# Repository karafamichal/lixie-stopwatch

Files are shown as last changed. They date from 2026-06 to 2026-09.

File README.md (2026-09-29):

# Lixie StopWatch

An open-source, Wi-Fi-connected time-tracking device that combines retro
Lixie (pseudo-Nixie) tube aesthetics with modern IoT. Tap a touch screen,
pick a client, project, app category and tool, watch the LED digits count up, and submit
the session to a self-hosted backend with one tap. All clients, projects
and time logs live on a Flask + SQLite server you control; a React
dashboard gives you full CRUD, live status, reports and a remote-control
mirror of every device's screen.

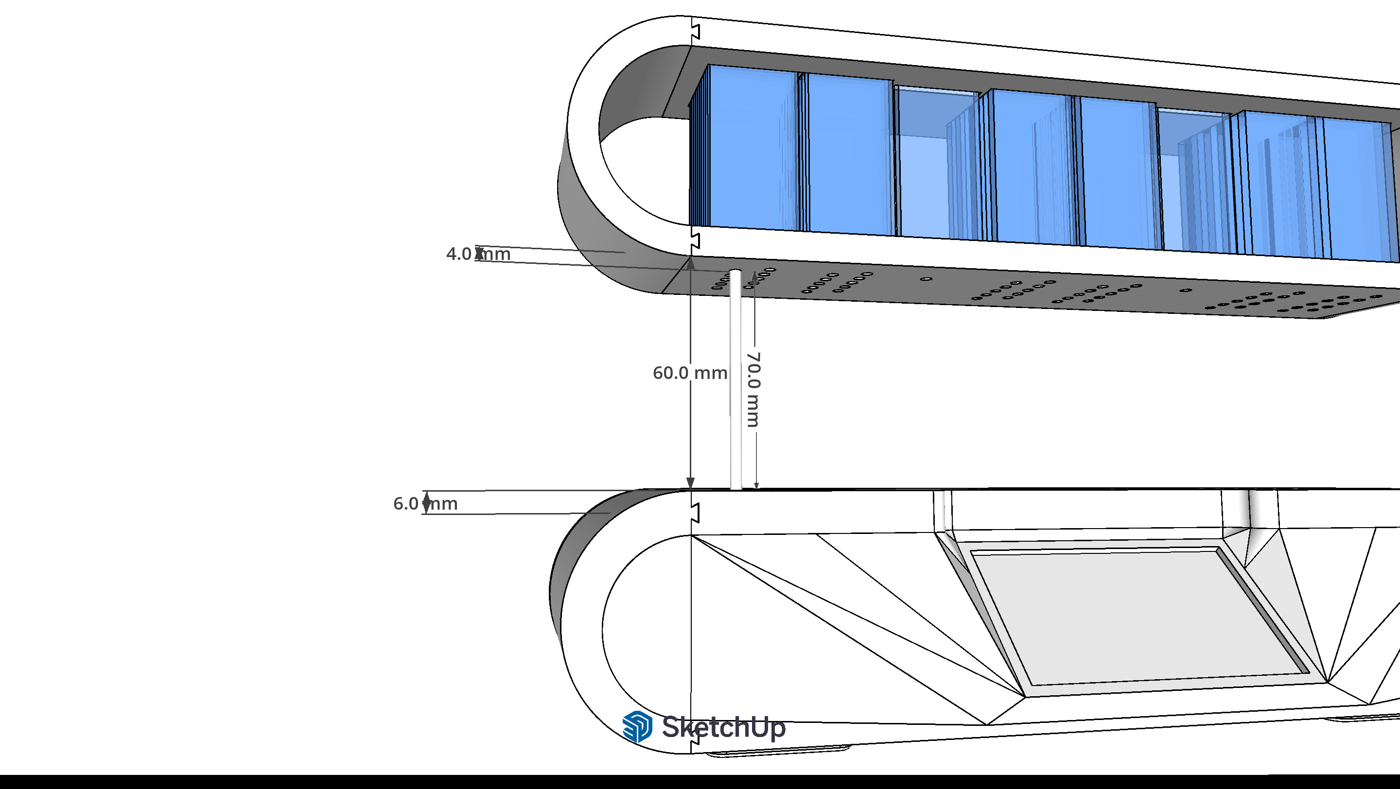
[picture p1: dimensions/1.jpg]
Front view


---

## What it does

* **6-digit Lixie display (HH:MM:SS)** — 75 WS2812B LEDs on 3× 5×5 boards,
  light shining through engraved cast-acrylic tiles to give a floating
  3-D digit effect. The two colon dots flip on/off in lock-step with the
  visible seconds.
* **Touch UI on a 3.2" Nextion display** — guided picker walks you
  through **client → project → category → app**, then Start. The
  category step groups your apps so you don't have to scroll past every
  tool. Pause / Continue / Stop / Discard on screen, with the project
  name shown in its own colour during a session.
* **Breadcrumb navigation** — each selection screen's header shows the
  path you've taken (e.g. `Acme Corp / Site redesign / Design`), so it's
  always clear how deep you are.
* **Wi-Fi onboarding via captive portal** — no need to flash credentials
  into the firmware. Plug in a fresh device, it brings up
  `LixieStopWatch-Setup`, you join it from a phone and pick your home /
  office network from a list.
* **Self-hosted Flask backend + React dashboard** — clients, projects,
  pricing, time logs, devices and reports. Mobile-friendly UI works on
  phones too.
* **Live state over WebSocket** — the dashboard sees every device's
  running state within ~1 s and renders a per-second timer that drifts
  forward locally between server pushes.
* **Remote control mirror** — a faithful 400×240 React render of the
  device's screen; click anywhere on it to inject a touch as if you'd
  tapped the physical Nextion. Operate the unit blind from the dashboard.
* **Per-device LED + display settings** — clock colour, LED brightness,
  an independent colour for the blinking colon dots, **Nextion backlight
  brightness (0–100 %; 0 = display off)**, and an **auto-sleep timeout**
  with an optional "also sleep on idle" toggle. All editable from the
  dashboard and persisted in NVS on the device.
* **English / German touch-screen UI** — every label on the Nextion
  display is translated. Switch on the device itself (☰ → Settings →
  *Language: English / Deutsch*, with live preview before you Save) or
  from the dashboard's device settings; the choice is persisted in NVS
  and the dashboard's remote-control mirror follows it automatically.
* **Auto-sleep view** — after the configured timeout the touch display
  dims to a minimalist icon-only screen (stopwatch glyph while running,
  coffee cup while paused or idle) so the panel isn't distracting in a
  shared workspace. Tap anywhere to wake back to where you were.
* **Weather + RSS news on the idle screen** — auto-derived from public
  IP, no API keys required. Headline rotates every 8 s and the
  background fetch only runs while the device is idle so timing during a
  session is never disturbed.
* **Offline-safe saving** — if the server can't be reached when you save
  a session, the device keeps it (up to 16) and re-sends it once a minute
  while idle. The dashboard shows how many are waiting per device.
* **Pomodoro mode** — optional focus blocks (e.g. 25 min): the LED digits
  count down, the session pauses for the break (green countdown), and the
  digits blink when it's time to continue.
* **"Forgot to start?" reminder** — after a configurable idle stretch on
  the home screen the device asks, and the LEDs blink until someone taps.
* **Night mode** — the LED matrix dims (or switches off) during set hours,
  but lights up normally while a session is running.
* **Firmware updates over Wi-Fi** — upload a `.bin` in the dashboard
  (Settings → Device firmware) and install it per device; the device waits
  until no session is running, verifies the image and restarts.
* **Dashboard extras** — English / German UI, light / dark theme, login
  password, hour budgets per project with warnings, CSV export of time
  logs, printable billing statements and reports (save as PDF), currency
  setting, and one-click database backup / restore.

---

## Project layout

```
nextion-stopwatch/     ESP32-S3 firmware (Arduino sketch + headers)
web-dashboard/
  backend/             Flask REST API + WebSocket hub + SQLite
  dashboard/           React + Vite + Tailwind admin SPA
3d/                    STL files for the case (print-ready)
dimensions/            Photos with measurements + assembly references
Lixie StopWatch — Build Estimate.xlsx
                       Per-unit BOM and time estimate (live formulas)
API.md                 REST + WebSocket reference
nextion-stopwatch/HMI_SETUP.md
                       Steps to build the minimal Nextion HMI file
install.sh             One-shot installer for the backend on a server
lixie-stopwatch.service
                       Systemd unit installed by install.sh
LICENSE                MIT
```

---

## Bill of materials — what one unit costs you

Slovak retail prices (techfun.sk + a hobby laser-cut service), mid-2026.
**Power supply, switch and heavy cabling are not included** because they
depend on how bright you run the LEDs (USB-C from the dev board is enough
at low/medium brightness; for full brightness on all 75 LEDs use a
separate 5 V / 5 A+ supply).

| Item | Qty | Unit | Total |
|---|---:|---:|---:|
| ESP32-S3 N16R8 dev board | 1 | 9.65 € | 9.65 € |
| Nextion 3.2" touch display | 1 | 49.20 € | 49.20 € |
| WS2812 5×5 RGB LED matrix board | 3 | 4.70 € | 14.10 € |
| Wires for connecting everything | 1 | 6.00 € | 6.00 € |
| 3 mm optical fibre, 5 m | 5 m | 0.75 €/m | 3.75 € |
| **Electronics subtotal** | | | **82.70 €** |
| Cast plexiglass sheet (3 mm) | 1 | 8.00 € | 8.00 € |
| Laser cutting + engraving (paid service, ~45 min) | 1 | 45.00 € | 45.00 € |
| **Optics subtotal** | | | **53.00 €** |

**3D-printed case — pick one:**

| Scenario | Detail | Cost |
|---|---|---:|
| A. You own a 3D printer | 500 g PETG + ~1.7 kWh (our reference: Prusa MK4s, 19 h 14 min) | 13.00 € |
| B. You pay a 3D-print service | 500 g PETG @ ~0.12 €/g | 60.00 € |

**Grand totals**

| Scenario | Total per unit |
|---|---:|
| **A — own 3D printer** | **148.70 €** |
| **B — paid print service** | **195.70 €** |
| A* — AliExpress route + own printer (3–5 week shipping wait) | 121.65 € |
| B* — AliExpress route + paid print | 168.65 € |

Full breakdown with live formulas, alternatives and assumptions:
[`Lixie StopWatch — Build Estimate.xlsx`](Lixie%20StopWatch%20%E2%80%94%20Build%20Estimate.xlsx).

### Tools / consumables you'll also need
Soldering iron, helping-hands stand, multimeter, USB-C cable, hot-glue or
super-glue for fibre seats, fine sandpaper for the laser-cut tiles.

---

## 3D-printable parts

All STL files are in [`3d/`](3d/). Print orientation, supports and
materials are noted below. Total filament for the full set: **≈ 500 g
PETG**, total print time **≈ 19 h 14 min on a Prusa MK4s** (0.2 mm layer
height, 15 % gyroid infill, no supports needed if you respect the
overhang directions below).

| File | What it is | Notes |
|---|---|---|
| `esp-top.stl` | Top shell of the electronics bay | Print right-side-up |
| `esp-back-wall.stl` | Rear wall with cable cut-outs | — |
| `esp-bootom-new.stl` | Main bottom plate of the electronics bay | — |
| `esp-bootom-left.stl` / `esp-bootom-right.stl` | Side plates | Print with the mounting boss down |
| `numbers-backwall.stl` | Back wall behind the digit matrices | Black PETG looks best |
| `glass-fullv2.stl` | Main front frame holding the engraved tiles | — |
| `glass-full-top-v2.stl` | Cap that closes the front frame from above | — |
| `glass-side2x.stl` | Side spacer × 2 (print twice) | — |
| `display-lixie-final2.stl` | Bezel for the Nextion touch panel | Tight fit — calibrate flow |
| `foot.stl` | Foot rest, print ×2 | — |

---

## Dimensions & assembly references

Pictures with measurements live in [`dimensions/`](dimensions/). They
show how everything fits together; numbers on them match the STLs above.

| Picture | What it shows |
|---|---|
|  | Assembled unit, front |
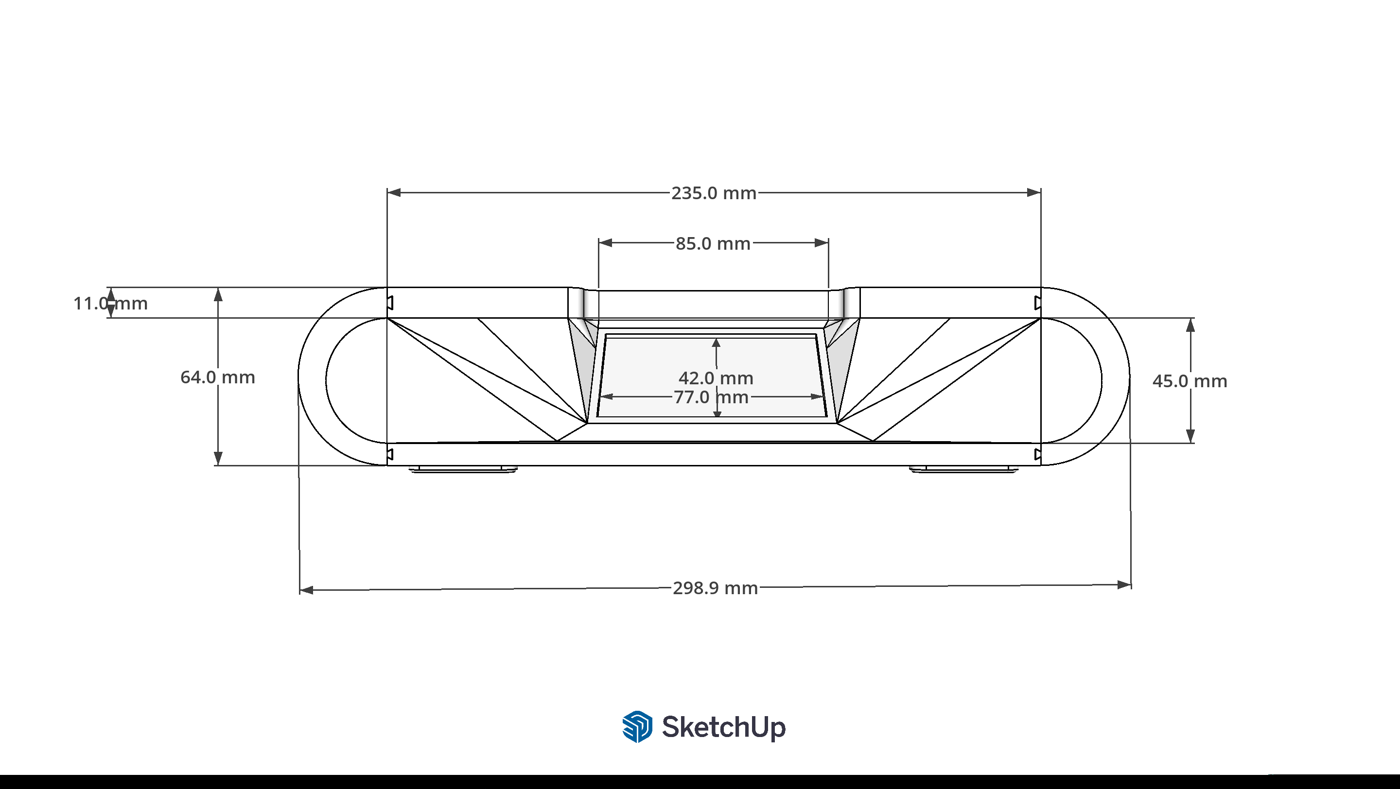
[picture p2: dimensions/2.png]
|  | Front-frame dimensions |
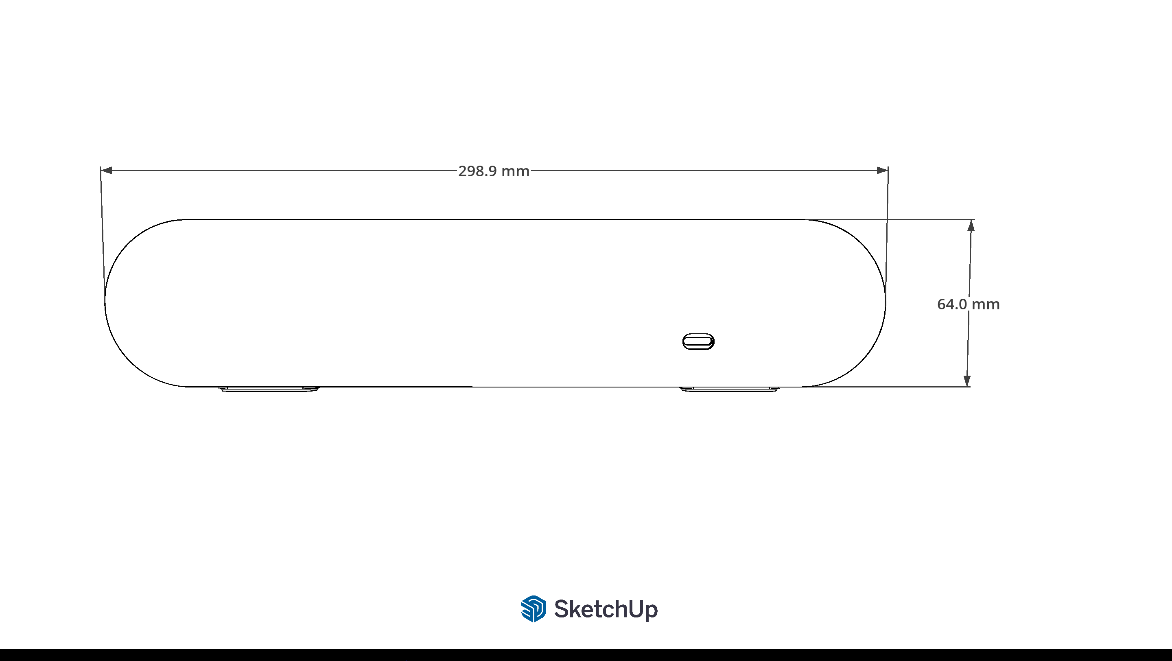
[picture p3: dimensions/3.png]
|  | Side profile |
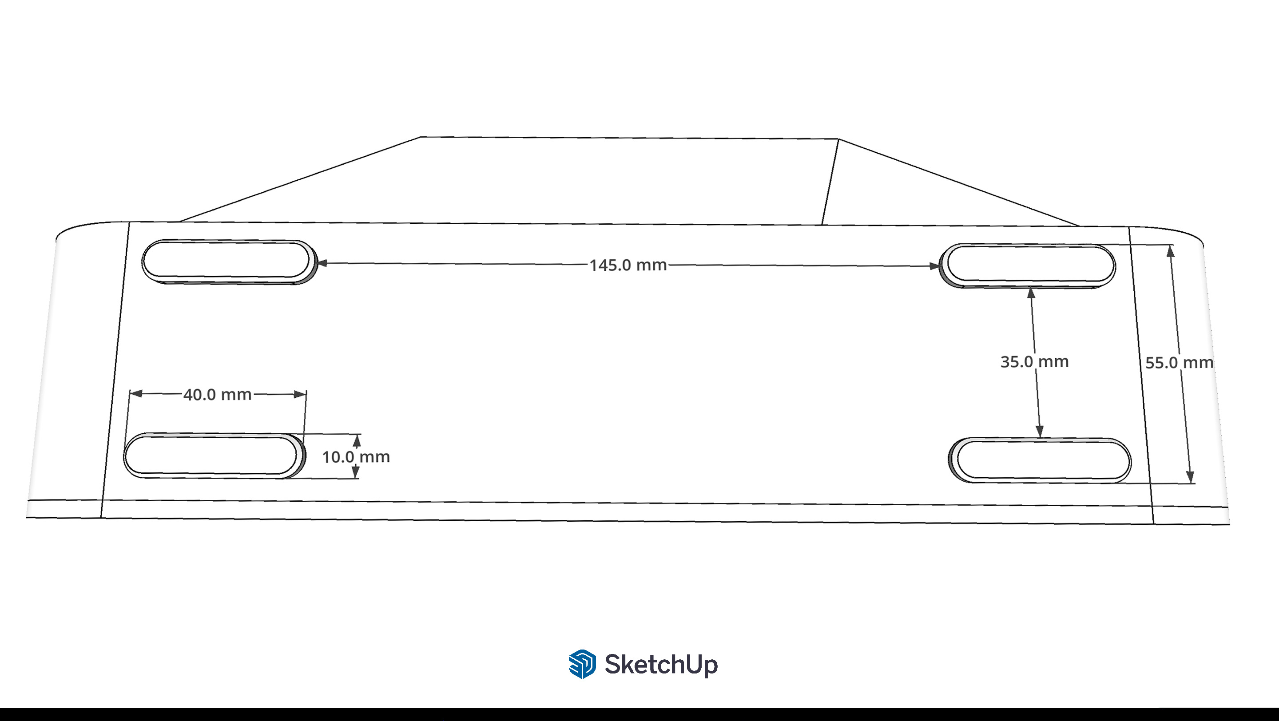
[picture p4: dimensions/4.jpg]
|  | Engraved tile stack-up |
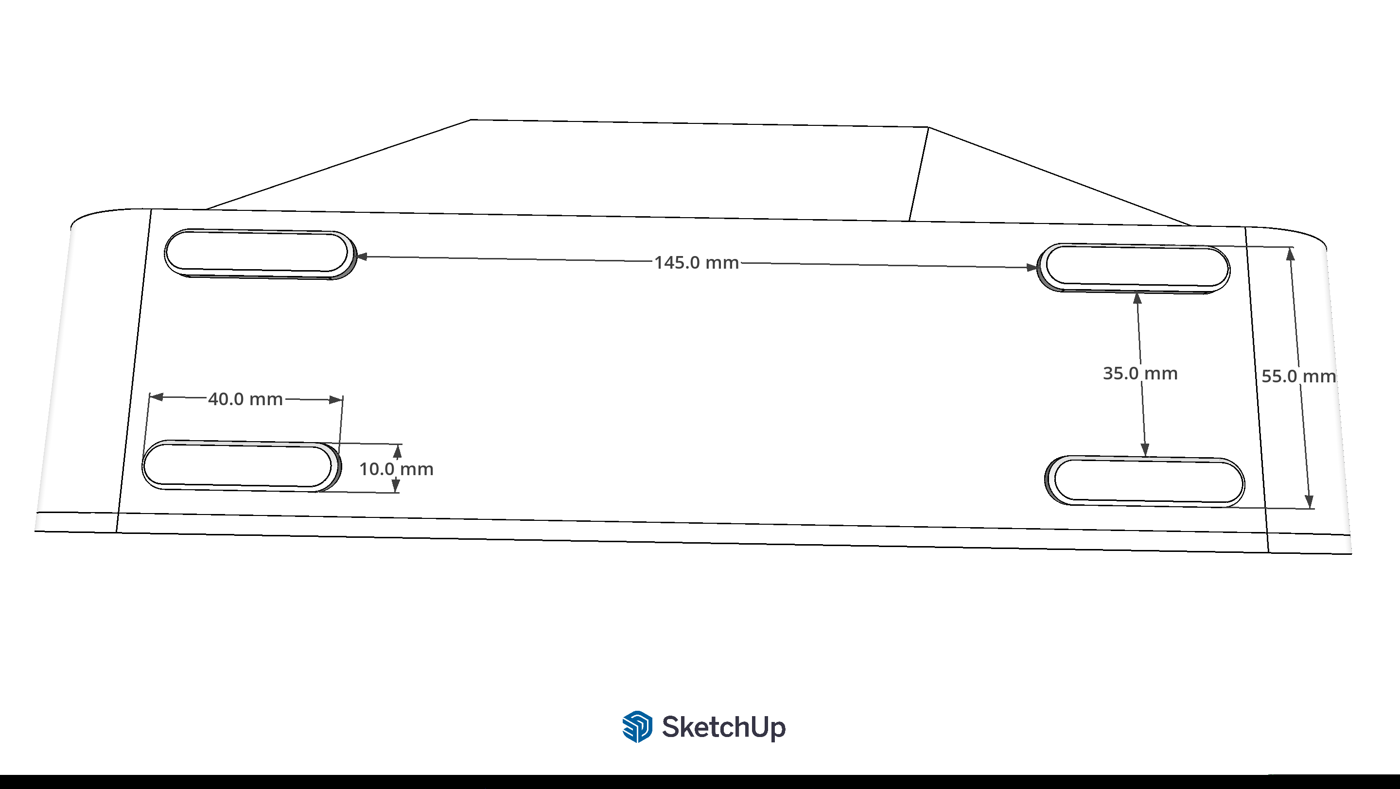
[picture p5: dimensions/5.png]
|  | Back-wall layout |
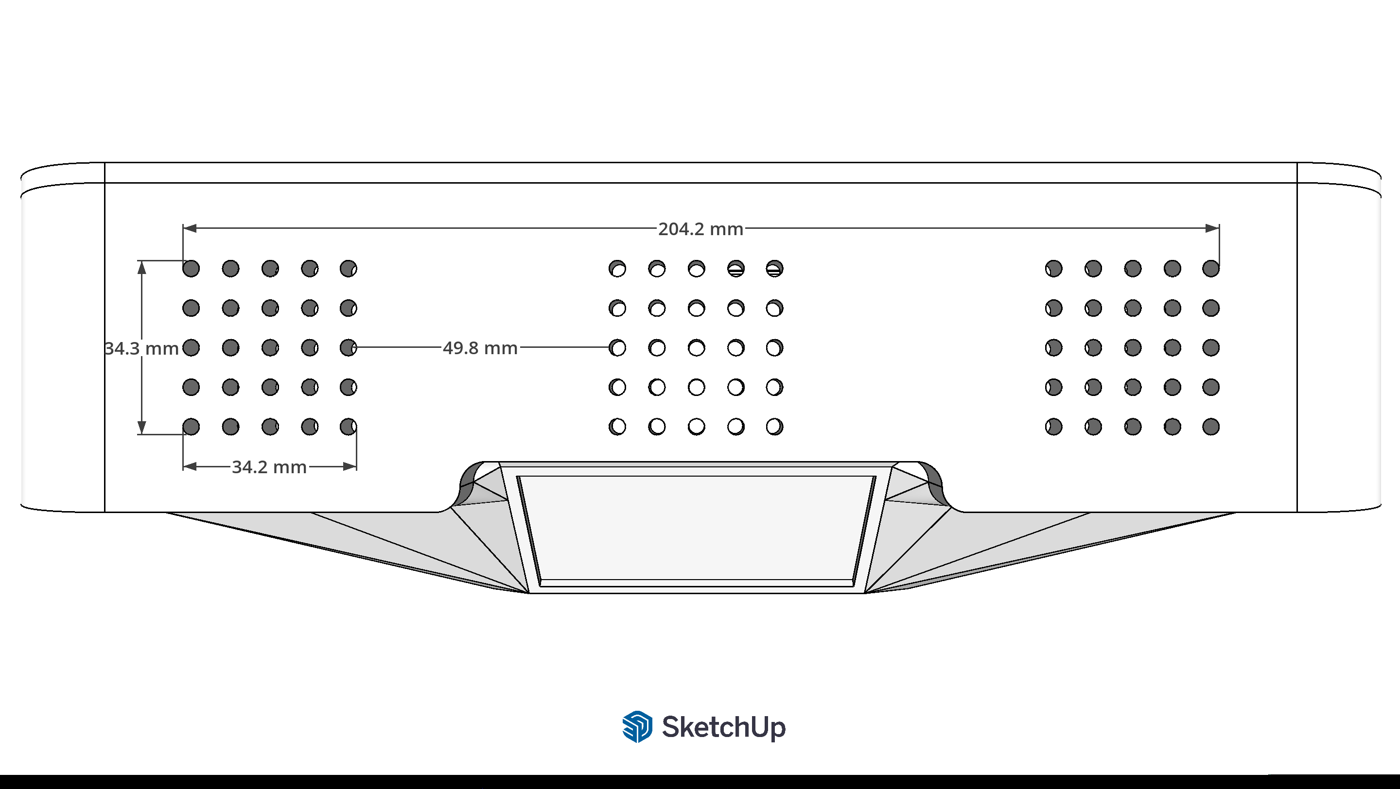
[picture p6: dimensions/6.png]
|  | Matrix-board placement grid |
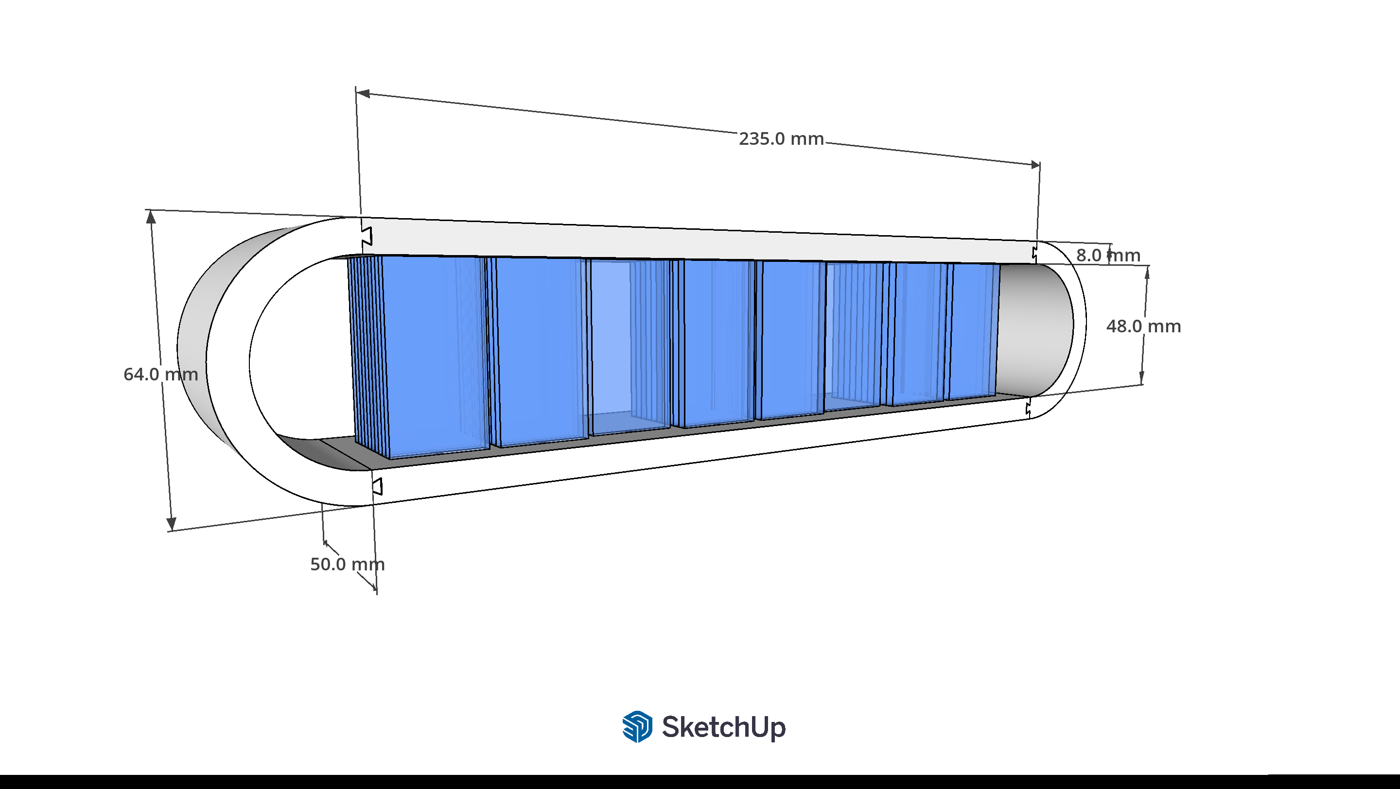
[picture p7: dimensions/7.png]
|  | Optical-fibre routing |
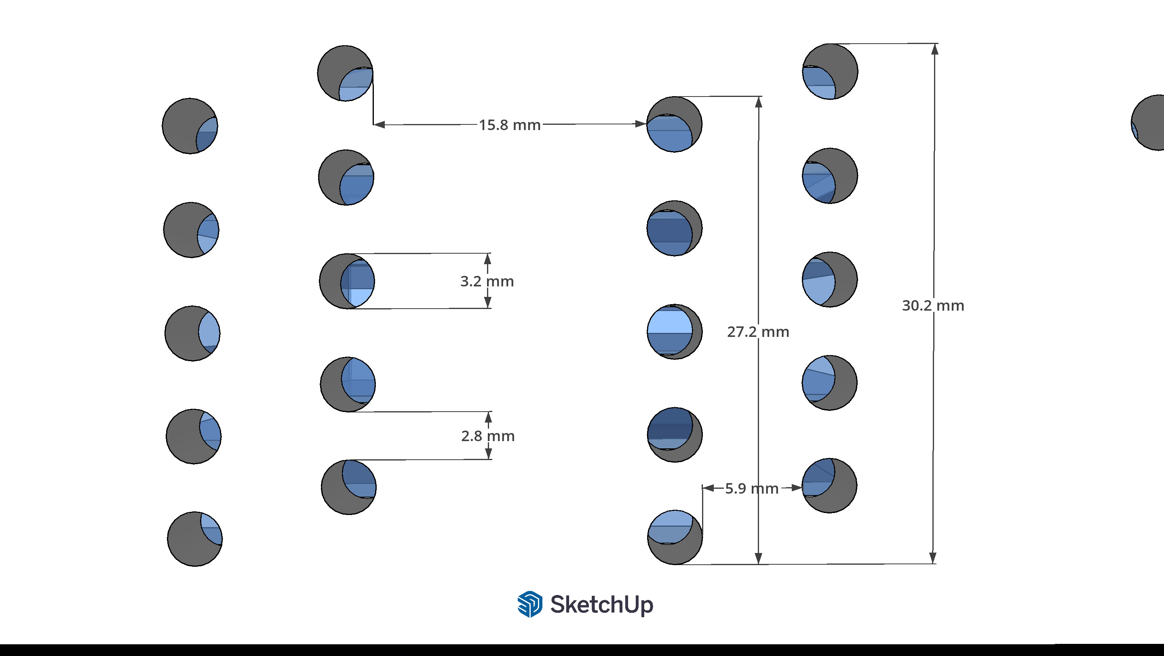
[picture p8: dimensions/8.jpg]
|  | Nextion bezel mounting |
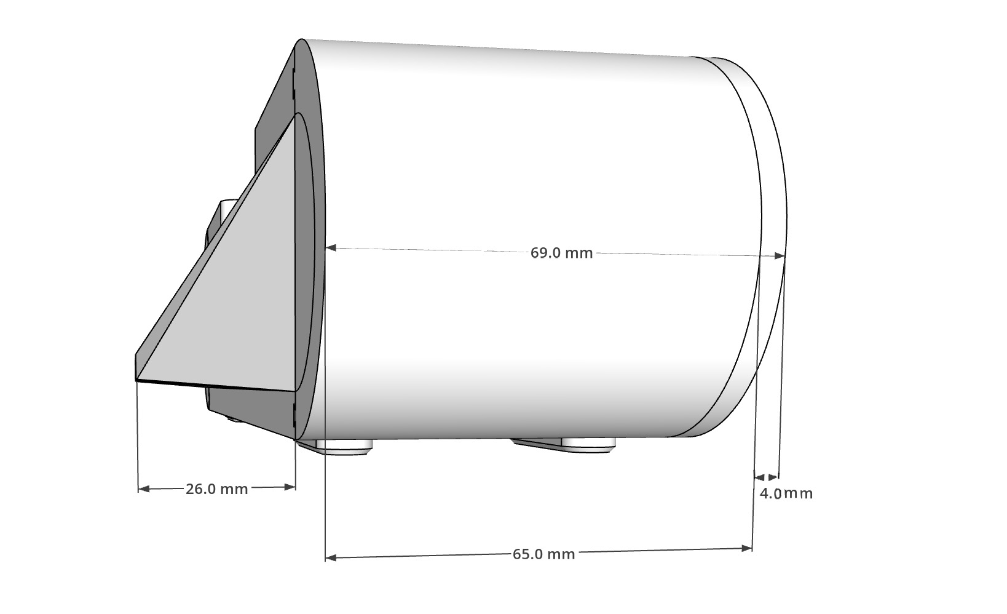
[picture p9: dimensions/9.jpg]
|  | Cable run for the LED chain |
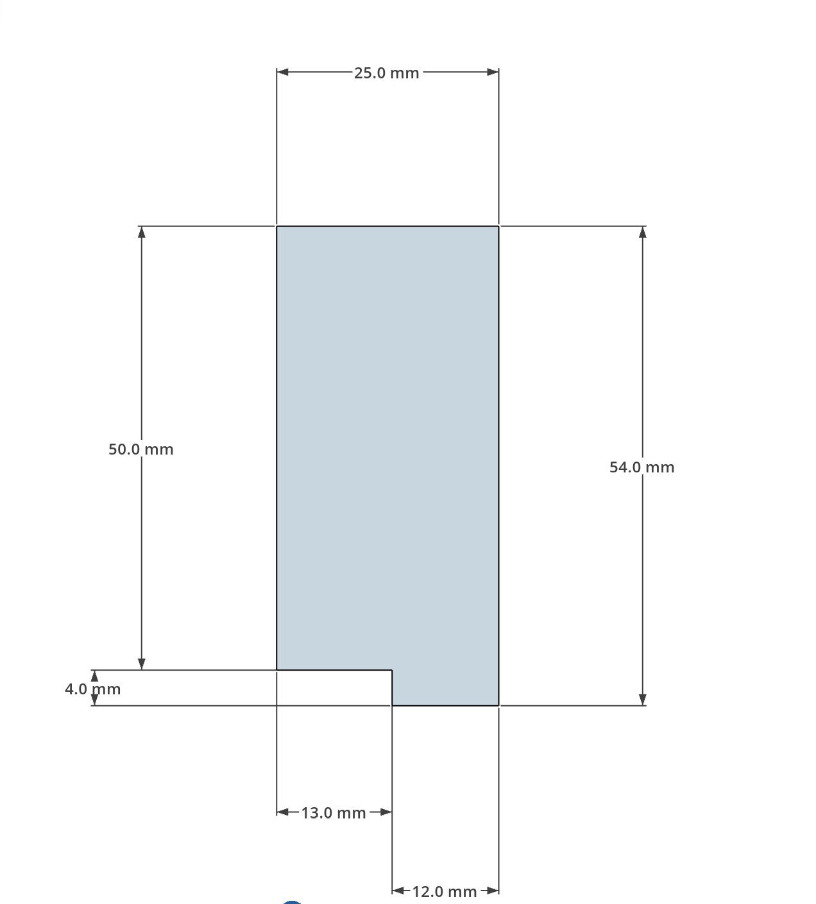
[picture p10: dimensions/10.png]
|  | ESP32 + Nextion wiring diagram |
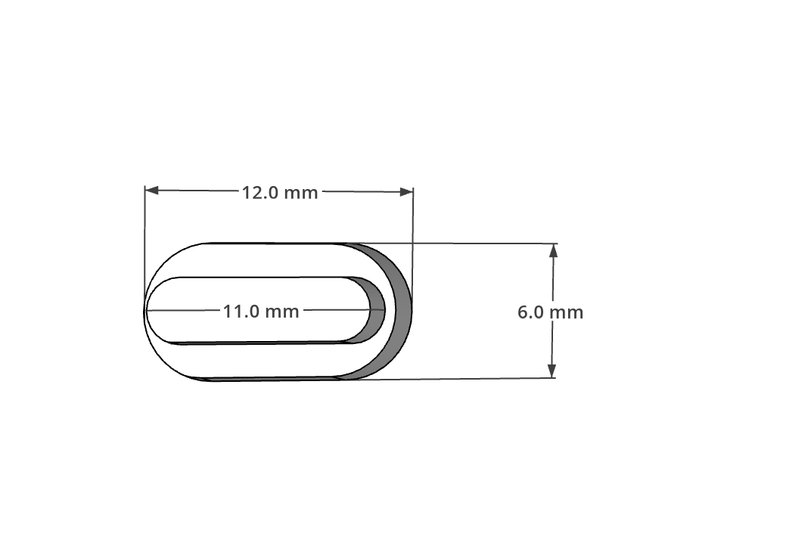
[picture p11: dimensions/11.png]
|  | Foot mounting |
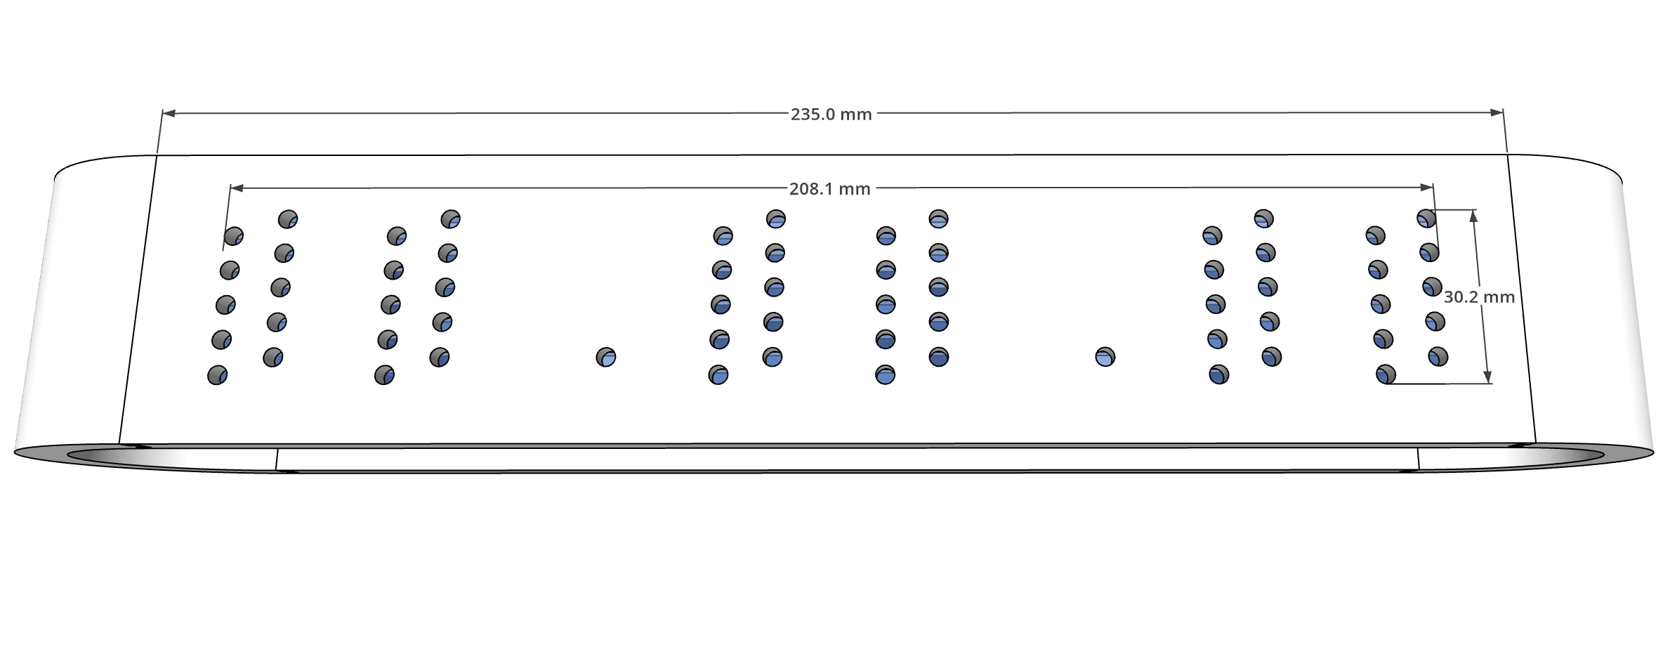
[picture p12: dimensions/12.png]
|  | Final exploded view |

---

## Build & assembly walk-through

1. **Print the case.** All 11 STLs from `3d/`. PETG is recommended near
   the power input; PLA is fine for the front frame.
2. **Cut 60 engraved tiles** — 10 layers of digits 0–9 per digit × 6
   digits — from 3 mm cast acrylic on a laser cutter. Vector source is
   embedded in the STL set; any hobby laser service can do this for you
   from the included engraving template.
3. **Solder the LED chain.** WS2812B 5×5 boards in series: DIN of board 1
   to GPIO 5, DOUT to DIN of board 2, etc. Insert each colon LED at the
   indices defined in `nextion-stopwatch/ledmap.cpp`.
4. **Wire the Nextion.** See [`nextion-stopwatch/HMI_SETUP.md`](nextion-stopwatch/HMI_SETUP.md)
   — it covers the pinout (GPIO 17/18 UART) and how to build the minimal
   HMI file from scratch.
5. **Slot the engraved tiles into the front frame** with optical fibres
   threaded from each LED to its tile. Refer to `dimensions/7.png` for
   the routing pattern.
6. **Close up the case**, plug in USB-C, and follow [First boot](#first-boot).

---

## Server installation (Linux, one-shot script)

The Flask backend + React dashboard live on any machine with Python 3.11+,
Node 18+ and a network reachable by the stopwatches. The included
[`install.sh`](install.sh) does everything for Debian/Ubuntu.

```bash
# On the server, as a normal user
unzip lixie-stopwatch-<version>.zip      # or git clone …
cd lixie-stopwatch
sudo bash install.sh
```

What the script does:

1. `apt install` Python venv tooling, Node + npm, build tools.
2. Creates a system user/group called **`lixie`**.
3. Copies the source tree to `/opt/lixie-stopwatch/`.
4. Creates a Python virtualenv at `/opt/lixie-stopwatch/venv/` and runs
   `pip install -r backend/requirements.txt`.
5. Runs `npm ci && npm run build` in the dashboard, copies the build
   into `backend/static/` so Flask serves the SPA on port 5000.
6. Installs `lixie-stopwatch.service` to `/etc/systemd/system/`, enables
   it and starts it.

When it finishes, the dashboard is reachable at `http://<server>:5000/`
and the API at `http://<server>:5000/api/v1/`. The database file lives
at `/opt/lixie-stopwatch/backend/instance/lixie.db` and is preserved on
re-runs of the script.

Re-run `sudo bash install.sh` after any code update to rebuild and
restart — the script is idempotent and the SQLite database in
`instance/` is excluded from the rsync.

### Verifying
```bash
systemctl status lixie-stopwatch.service
journalctl -u lixie-stopwatch.service -f
curl -s http://localhost:5000/api/v1/stats | python3 -m json.tool
```

### Reverse proxy / HTTPS
If you want HTTPS or a friendly hostname, point an Nginx / Caddy / Apache
vhost at `http://127.0.0.1:5000`. The WebSocket at `/api/v1/ws` upgrades
correctly through standard reverse-proxy WS configs — no extra path
gymnastics needed.

---

## Firmware install (ESP32-S3)

The firmware is a plain Arduino sketch in
[`nextion-stopwatch/`](nextion-stopwatch/).

1. Install **Arduino IDE 2.x**, add the **esp32 by Espressif Systems**
   board manager URL
   `https://espressif.github.io/arduino-esp32/package_esp32_index.json`
   and install the latest package.
2. Pick board **ESP32S3 Dev Module**, PSRAM **OPI PSRAM**, Flash size
  **16 MB**, and partition scheme **16M Flash (3MB APP/9.9MB FATFS)**.
  The default scheme has a 1.25 MB app slot and is too small for this
  firmware.
3. Install the libraries (Sketch ▸ Include Library ▸ Manage Libraries):
   - `FastLED`
   - `ArduinoJson` (v7)
   - `WebSockets` by Markus Sattler
4. Open `nextion-stopwatch/nextion-stopwatch.ino` and flash.

Later updates can go over Wi-Fi: bump `FW_VERSION` in `config.h`, use
**Sketch ▸ Export Compiled Binary**, upload the `.ino.bin` under
Settings → Device firmware in the dashboard, then press the install button
next to the device on the Devices page. This needs a partition scheme with
two app slots — the one above has them.

On a brand-new device the firmware tries the placeholder Wi-Fi in
`config.h` (`changeme` / `changeme`), fails, and brings up the captive
portal — keep reading.

---

## First boot

1. Power the device.
2. On a phone or laptop, join the open Wi-Fi **`LixieStopWatch-Setup`**.
3. A captive portal should open automatically — if not, browse to
   `http://192.168.4.1/`.
4. Pick your home / office Wi-Fi from the list, enter the password, hit
   **Save**. If your dashboard server is not the build-time default, fill
   in its IP / hostname and port on the same page. The device stores it
   all to NVS and reboots.
5. From then on it auto-connects to that network at every boot. To
   change networks later, hold the front face during boot until you see
   the AP mode banner — or temporarily move it out of range of the saved
   network and it'll fall back to AP mode by itself.

Now go to the dashboard at `http://<your-server>:5000/`:

* **Devices** page shows your stopwatch as **Online** within ~5 seconds
  of the first WebSocket connect.
* Click the **palette** icon to set per-device matrix settings:
  - **Clock colour** and **LED matrix brightness** (Low / Med / High / Max)
  - **Colon dot colour** — independent from the clock colour, with a
    *link* toggle that keeps them in sync when on
  - **Touch display brightness** — 0–100 % slider; 0 % turns the Nextion
    backlight all the way off
  - **Auto-sleep** — seconds of inactivity before the screen dims to the
    icon-only sleep view (0 disables); a switch lets you extend the
    timeout to the idle screen too
  - **Touch display language** — English or Deutsch for the Nextion UI
    (the dashboard itself stays in English)
* Click the **mirror screen** icon to remote-control the unit from the
  browser. The mirror reproduces every screen — including the sleep
  view — and clicks are converted to device pixels and posted as a
  synthetic touch.
* In **Clients** create your first client, then a project under it.
  Under **Pricing** add any custom apps you want grouped per category
  (Design / Development / Office / …). On the device the picker walks
  the user through **Client → Project → Category → App** with three
  rows per screen so there's no scrolling past every tool.

---

## What you might want to change in the code

Out of the box the captive portal + the pre-configured RSS feed mean
**most people don't have to edit anything**. If you want to:

| What | Where |
|---|---|
| Default server hostname / IP and port (the captive setup page can override them) | `nextion-stopwatch/config.h` → `WS_HOST`, `WS_PORT` |
| Default LED brightness and colour | `nextion-stopwatch/config.h` → `LED_BRIGHTNESS`, `COL_ACCENT` (only used until the user overrides them from the dashboard) |
| Time zone | `config.h` → `TZ_STRING` (POSIX TZ syntax) |
| RSS news feed | `config.h` → `NEWS_RSS_URL` |
| Weather fallback city when ip-api.com geolocation fails | `config.h` → `WEATHER_FALLBACK_*` |
| Hardware ID (must be unique per physical unit if you have more than one) | `config.h` → `HARDWARE_ID` |
| LED-to-digit mapping if a segment is dark after soldering | `nextion-stopwatch/ledmap.cpp` → `ledIndex[][]` |
| Service paths / install root | `install.sh` and `lixie-stopwatch.service` |

---

## Power notes

* **USB-C only** — fine at low / medium brightness. The ESP32-S3 dev
  board's USB input can supply ~500 mA, enough for the display and the
  LEDs at brightness up to ~80/255.
* **External 5 V supply** — required if you want full brightness on all
  75 LEDs. Worst case draw is ~4.9 A (75 × 60 mA + the ESP32 and
  Nextion). A 5 V / 5 A+ switching supply is enough; wire it through
  your own switch and a fused barrel jack.
* Add a **1000 µF** electrolytic capacitor across the 5 V rail at the
  head of the LED chain if you see the first frame flash on power-on.

---

## License

[MIT](LICENSE). Use, copy, modify, fork, sell, do whatever you want —
just keep the copyright notice. The 3D models in [`3d/`](3d/) and the
Nextion HMI assets are released under the same terms.

---

## Credits

Built by the Lixie StopWatch team as an Erasmus+ school project (Erfurt
2026). Open-sourced so anyone can build, hack and improve.

Pull requests welcome — especially better case designs, alternative
display drivers, and translations of the dashboard UI.

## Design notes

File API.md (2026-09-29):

# Lixie StopWatch — API Reference

Base URL: `http://<server>:5000/api/v1`

All request bodies are JSON (`Content-Type: application/json`).
All responses are JSON. Dates are ISO 8601 strings (`2026-05-26T14:30:00`).

The server exposes a REST API for everything that doesn't need to be live
(CRUD, reports) and a single WebSocket channel for live state push and
remote control. ESP32 stopwatches and the React dashboard both use the same
endpoints.

### Authentication

The dashboard can be locked with a password (Settings → Dashboard password).
Until one is set, every endpoint is open. Once it is set, every endpoint
answers `401 {"error": "login required"}` without a session cookie, **except**
the ones the ESP32 uses, which stay open so devices need no credentials:

`GET /clients`, `GET /projects`, `GET /apps`, `POST /timelogs`,
`POST /devices/heartbeat`, `GET /firmware/<token>.bin` and the WebSocket
(devices may push `state`; a `subscribe` from a browser without a session
closes the socket).

| Endpoint | Body | Notes |
|---|---|---|
| `GET /auth` | – | `{ "enabled": bool, "authenticated": bool }` |
| `POST /auth/login` | `{ "password": "…" }` | Sets a 30-day session cookie. Wrong password: `401` after a 1 s delay. |
| `POST /auth/logout` | – | Clears the session. |
| `PUT /auth/password` | `{ "current": "…", "new": "…" }` | Sets, changes or (with an empty `new`) removes the password. `current` is required once a password exists; `new` needs at least 6 characters. |

---

## Data model overview

```
client  ──<  project  ──<  time_log  >──  app
                                 \
                                  >──  device
```

One `time_log` row = one completed work session: **who worked, on what
project, for which client, using which app, for how long, on which device.**

### Tables

| Table | Notable columns | Cascade |
|---|---|---|
| `client` | `name`, `active`, `color`, `logo`, `created_at` | — |
| `project`  | `name`, `client_id`, `active`, `color`, `logo`, `completed`, `completed_at` | deleted when client is deleted |
| `app` | `name`, `category`, `icon`, `color`, `logo`, `is_builtin`, `hourly_rate`, `active` | — |
| `device` | `hardware_id`, `label`, `last_seen` | — |
| `time_log` | `device_id`, `client_id`, `project_id`, `app_id`, `start_timestamp`, `duration_seconds`, `notes`, `status`, `synced_at` | `client_id`/`project_id` delete cascades; `app_id`/`device_id` are nullable and kept on delete |

---

## Clients

### `GET /clients`

Returns all clients ordered by name.

```json
[
  {
    "id": 1,
    "name": "Acme Corp",
    "active": true,
    "color": "#FF8000",
    "logo": null,
    "created_at": "2026-05-01T10:00:00"
  }
]
```

### `POST /clients`

| Field | Type | Required | Default |
|---|---|---|---|
| `name` | string | yes | — |
| `active` | boolean | no | `true` |
| `color` | string `#RRGGBB` | no | `#FF8000` |
| `logo` | data URL string | no | `null` |

Returns `201` with the created object.

### `PUT /clients/<id>`

Any subset of `name`, `active`, `color`, `logo`. Returns the updated object.

### `DELETE /clients/<id>`

Cascades: all projects and time logs for this client are also deleted.
`204 No Content`.

---

## Projects

### `GET /projects?client_id=<id>`

**Active** projects only — what the ESP32 consumes when building the
project picker.

```json
[
  {
    "id": 7,
    "client_id": 3,
    "client_name": "Acme Corp",
    "client_color": "#FF8000",
    "client_logo": null,
    "name": "Website Redesign",
    "active": true,
    "color": "#2D8CFF",
    "logo": null,
    "completed": false,
    "completed_at": null,
    "created_at": "2026-05-10T09:00:00"
  }
]
```

### `GET /projects/all?client_id=<id>`

Every project including inactive and completed ones, each with two extra
fields: `budget_hours` (planned hours, `null` = no budget) and
`tracked_seconds` (total logged time).

All projects (active **and** inactive). Dashboard only.

### `POST /projects`

| Field | Type | Required | Default |
|---|---|---|---|
| `name` | string | yes | — |
| `client_id` | integer | yes | — |
| `active` | boolean | no | `true` |
| `color` | hex | no | `#FF8000` |
| `logo` | data URL | no | `null` |

Returns `201`.

### `PUT /projects/<id>`

`POST /projects` and `PUT /projects/<id>` accept `budget_hours` (number ≥ 0;
`null`, `""` or `0` removes the budget), and `led_style` — how the LED
digits look during a session of this project (`""` = client colour):

| `led_style` | Meaning |
|---|---|
| `""` | Plain colour |
| `d:#RRGGBB,…` (6 colours) | One colour per digit, H H M M S S |
| `c:SEC:#RRGGBB,…` (2–8 colours) | All digits fade through the colours, one round every `SEC` (1–3600) seconds |

Any subset of the create fields, plus:

| Field | Type | Notes |
|---|---|---|
| `completed` | boolean | When set `true` the project is auto-deactivated and `completed_at` is stamped to `now`. Setting back to `false` clears `completed_at`. |

### `GET /projects/<id>/billing`

Per-app time and earnings breakdown for one project.

```json
{
  "project_id": 7,
  "project_name": "Website Redesign",
  "total_seconds": 36000,
  "total_earnings": 950.00,
  "breakdown": [
    {
      "app_id": 2,
      "app_name": "Photoshop",
      "app_icon": "🎨",
      "app_color": "#31A8FF",
      "hourly_rate": 95.00,
      "seconds": 18000,
      "hours": 5.0,
      "earnings": 475.00
    }
  ]
}
```

The billing response also carries `client_name`, `first_log` and
`last_log` (ISO timestamps of the earliest and latest time log), used by the
dashboard's printable billing statement.

### `DELETE /projects/<id>`

Cascades all time logs for this project. `204`.

---

## Apps (a.k.a. Pricing tools)

### `GET /apps`

Active apps only, ordered by category then name. Used by the ESP32.

```json
[
  {
    "id": 2,
    "name": "Photoshop",
    "category": "Design",
    "icon": "🎨",
    "color": "#31A8FF",
    "logo": null,
    "active": true,
    "is_builtin": true,
    "hourly_rate": 95.00,
    "created_at": "2026-05-01T10:00:00"
  }
]
```

### `GET /apps/all`

All apps including inactive. Dashboard only.

### `POST /apps`

Create a **custom** (non-built-in) app.

| Field | Type | Default |
|---|---|---|
| `name` | string | required |
| `category` | string | `Other` |
| `icon` | string (emoji) | `🖥️` |
| `color` | hex | `#FF8000` |
| `hourly_rate` | float | `null` |
| `logo` | data URL | `null` |

### `PUT /apps/<id>`

For **built-in** apps only `active`, `hourly_rate` and `logo` can be
changed (name / category / icon / color stay locked). Custom apps accept
the full set.

### `DELETE /apps/<id>`

Returns `400` if `is_builtin`. Time logs that referenced this app keep
their `app_id` value — it's nullable, not cascaded.

---

## Time Logs

### `GET /timelogs`

List time logs, newest first. Filters:

| Param | Type | Description |
|---|---|---|
| `client_id` | integer | filter by client |
| `project_id` | integer | filter by project |
| `app_id` | integer | filter by app |
| `from` | `YYYY-MM-DD` | start of date range (inclusive) |
| `to` | `YYYY-MM-DD` | end of date range (inclusive) |

```json
[
  {
    "id": 42,
    "device_id": 1,
    "hardware_id": "esp32_lixie_001",
    "device_label": "Studio Device",
    "client_id": 3,
    "client_name": "Acme Corp",
    "project_id": 7,
    "project_name": "Website Redesign",
    "app_id": 2,
    "app_name": "Photoshop",
    "app_icon": "🎨",
    "app_color": "#31A8FF",
    "start_timestamp": "2026-05-26T14:00:00",
    "duration_seconds": 5400,
    "notes": "Homepage banner mockups",
    "status": "completed",
    "synced_at": "2026-05-26T15:30:00"
  }
]
```

### `POST /timelogs` — primary ESP32 endpoint

Submit a completed session.

| Field | Type | Required | Notes |
|---|---|---|---|
| `hardware_id` | string | no | Auto-creates a `device` row on first sight and updates `last_seen` on every submission. |
| `client_id` | integer | yes | Must exist. |
| `project_id` | integer | yes | Must exist. |
| `app_id` | integer | no | If omitted/`null`, the session is logged without an app. |
| `start_timestamp` | ISO 8601 | no | UTC preferred (trailing `Z` accepted). Defaults to server time if omitted. |
| `duration_seconds` | integer | yes | Total elapsed seconds the timer ran. |
| `notes` | string | no | Free-text memo. |
| `status` | string | no | `completed` / `pending` / `synced`. Defaults to `completed`. |

Returns `201` with the full time log object.

### `PUT /timelogs/<id>` / `DELETE /timelogs/<id>`

Edit / remove a single entry (dashboard).

---

## Devices

Devices are auto-registered the first time their `hardware_id` appears in
either a `POST /timelogs` call, a heartbeat, or a WebSocket connection.

### `GET /devices`

All known devices, most recently seen first.

```json
[
  { "id": 1, "hardware_id": "esp32_lixie_001", "label": "Studio Device", "last_seen": "2026-05-26T15:30:00" }
]
```

### `POST /devices/heartbeat`

Body: `{ "hardware_id": "esp32_lixie_001" }`. Touches `last_seen` so the
dashboard's online indicator stays accurate between time-log submissions.
First call also auto-registers the device. `204`.

### `PUT /devices/<id>`

Body `{ "label": "Studio Device" }`. Returns the updated device.

### `GET /devices/<id>/settings`

Read the currently-cached LED + display settings for one device.

```json
{
  "hardware_id":        "esp32_lixie_001",
  "color":              "#FF8000",
  "colon_color":        "#FF8000",
  "colon_linked":       true,
  "brightness":         150,
  "display_brightness": 100,
  "sleep_timeout_sec":  30,
  "sleep_on_idle":      false,
  "language":           "en",
  "pomodoro_min":       25,
  "break_min":          5,
  "reminder_min":       0,
  "night_start":        22,
  "night_end":          7,
  "night_brightness":   10,
  "online":             true
}
```

### `PUT /devices/<id>/settings`

Push new LED + display settings to a device. Any subset of fields may
be sent.

| Field | Type | Notes |
|---|---|---|
| `color` | `#RRGGBB` | Clock / stopwatch digit colour |
| `colon_color` | `#RRGGBB` | The two blinking colon dots (independent colour) |
| `clock_style` | `led_style` string | Per-digit colours or colour cycle for the clock (same format as projects' `led_style`); `""` = plain `color` |
| `demo` | boolean | Demo / showcase mode: rainbow animation instead of the idle clock. Sessions still display normally. |
| `colon_linked` | boolean | When `true` the colon colour automatically mirrors `color`; PUTting `colon_color` without an explicit `colon_linked` flips it to `false` |
| `brightness` | `0..255` | LED matrix brightness (single global FastLED setting) |
| `display_brightness` | `0..100` | Nextion backlight, in percent. `0` turns the backlight all the way off (controller still responds to commands). |
| `sleep_timeout_sec` | `0..65535` | Seconds of inactivity before the touch display dims to the icon-only sleep view. `0` disables auto-sleep entirely. |
| `sleep_on_idle` | boolean | When `true`, the sleep timeout also applies to the idle / home screen (coffee-cup icon). When `false`, sleep only triggers from the running session view. |
| `pomodoro_min` | `0..120` | Pomodoro focus block in minutes; `0` turns pomodoro off. The LEDs count down each block, then the session auto-pauses for the break. |
| `break_min` | `1..60` | Break length after each focus block. |
| `reminder_min` | `0..480` | Minutes on the home screen without a touch before the "Forgot to start?" prompt (LEDs blink). `0` = off. Suppressed during night mode. |
| `night_start`, `night_end` | `0..23` | Local hours of the night window (may wrap past midnight). Equal values turn night mode off. |
| `night_brightness` | `0..255` | LED brightness inside the night window (`0` = LEDs off). Normal brightness returns while a session runs. |
| `language` | `"en"` \| `"de"` | UI language of the Nextion touch screen. Also switchable on the device itself (Settings → Language); the device reports its current language in every state push and the server adopts that value, so the two never fight. |

The dashboard-only `colon_linked` flag is stripped before pushing to the
device — the firmware only ever sees `{type:"settings", color,
colon_color, brightness, display_brightness, sleep_timeout_sec,
sleep_on_idle, language}`. Settings are cached server-side and re-sent to the
device the moment it next connects.

Response includes the merged state plus `delivered: true|false`
(`false` = device is currently offline; the cached value will be replayed
on reconnect).

### `POST /devices/<id>/ota`

Tell a connected device to install the firmware uploaded via
`POST /firmware`. The device keeps the request until no session is running,
downloads `GET /firmware/<token>.bin`, verifies it against the `x-MD5`
header and reboots into it. Returns `{ "delivered": bool }` (`false` =
offline, nothing queued). Progress shows up as `ota_status` in the device's
state push.

### `POST /devices/<id>/remote/touch`

Inject a synthetic Nextion touch — used by the Remote Control modal in
the dashboard to operate the device as if you were tapping the physical
screen.

Body:

```json
{ "x": 200, "y": 120, "pressed": true }
```

| Field | Type | Range / default |
|---|---|---|
| `x` | integer | `0..399` (matches device screen) |
| `y` | integer | `0..239` |
| `pressed` | boolean | default `true` (the firmware acts on press, ignores release) |

Response `{ "delivered": true|false }` — `false` means the device was
offline and the touch was dropped (not queued).

### `DELETE /devices/<id>`

Remove the device row. Time logs from this device keep their `device_id`
(orphaned reference, kept for history).

---

## Server settings, backup, firmware

### `GET /settings` / `PUT /settings`

`{ "currency": "EUR" }` — ISO 4217 code used for rates, earnings and
statements. Amounts are stored as plain numbers and never converted.

### `GET /backup`

Downloads a consistent snapshot of the SQLite database
(`lixie-backup-YYYYMMDD-HHMM.db`).

### `POST /backup`

Multipart upload (`file`). The file must be a SQLite database that passes
`PRAGMA integrity_check` and contains the `client`, `project` and `time_log`
tables; it then **replaces all data**, including the dashboard password.

### `GET /firmware` / `POST /firmware`

`POST` takes a multipart `file`: an ESP32 app image (first byte `0xE9`,
max 4 MB — use Arduino IDE ▸ Sketch ▸ Export Compiled Binary). Only the
latest upload is kept. Both return
`{ "name", "size", "md5", "uploaded_at" }` (`GET` returns `null` before the
first upload).

### `GET /firmware/<token>.bin`

The image itself, for devices. The token changes with every upload, so the
URL can't be guessed and old links stop working.

---

## Stats

### `GET /stats`

```json
{
  "clients": 5,
  "active_clients": 4,
  "projects": 12,
  "active_projects": 9,
  "apps": 28,
  "timelogs": 347,
  "devices": 2,
  "week_seconds": 72000,
  "month_seconds": 540000
}
```

Week starts on Monday. Ranges are UTC-based.

---

## Reports

All four report endpoints share the same optional filters:

| Param | Type | Description |
|---|---|---|
| `from` | `YYYY-MM-DD` | start of range (inclusive) |
| `to` | `YYYY-MM-DD` | end of range (inclusive) |
| `client_id` | integer | limit to one client |
| `project_id` | integer | limit to one project |

### `GET /reports/daily`

Total tracked seconds per calendar day. Days with zero activity are not
included — the dashboard fills the gaps.

```json
[
  { "date": "2026-05-24", "seconds": 18000 },
  { "date": "2026-05-25", "seconds": 25200 }
]
```

### `GET /reports/by-client`

Total seconds and earnings per client, descending.

```json
[
  { "id": 3, "name": "Acme Corp", "color": "#FF8000", "seconds": 54000, "earnings": 1425.00 }
]
```

### `GET /reports/by-project`

Total seconds and earnings per project, descending. Includes the
`completed` flag so the dashboard can colour finished projects differently.

```json
[
  {
    "id": 7,
    "name": "Website Redesign",
    "color": "#2D8CFF",
    "completed": false,
    "client_name": "Acme Corp",
    "seconds": 36000,
    "earnings": 950.00
  }
]
```

### `GET /reports/by-app`

Total seconds per app, descending. Only apps with at least one log are
returned.

```json
[
  {
    "id": 2,
    "name": "Photoshop",
    "icon": "🎨",
    "color": "#31A8FF",
    "category": "Design",
    "seconds": 21600
  }
]
```

---

## Live state

### `GET /live`

A plain HTTP snapshot of every device's last-known state — useful for
cold-start renders in the dashboard before its WebSocket connection lands.

```json
[
  {
    "type": "device_state",
    "hardware_id": "esp32_lixie_001",
    "state": "running",
    "screen": "running",
    "paused": false,
    "elapsed_seconds": 1234,
    "client_id": 3, "client_name": "Acme Corp", "client_color": "#FF8000",
    "project_id": 7, "project_name": "Website Redesign", "project_color": "#2D8CFF",
    "app_id": 2, "app_name": "Photoshop",
    "category_name": "Design",
    "start_timestamp": "2026-05-26T14:00:00Z",
    "received_at": "2026-05-26T14:20:34Z"
  }
]
```

### `/api/v1/ws` — WebSocket

A single bidirectional channel used by both ESP32 devices and dashboards.

**Device → server (state push)**

The device sends a state message immediately on every state-or-screen
change, then every 1 s while active and every 5 s while idle.

```json
{
  "type": "state",
  "hardware_id": "esp32_lixie_001",
  "state": "running",
  "screen": "running",
  "paused": false,
  "elapsed_seconds": 1234,
  "language": "en",
  "fw": "1.1.0",
  "queued": 0,
  "ota_status": "waiting",
  "client_id": 3, "client_name": "Acme Corp", "client_color": "#FF8000",
  "project_id": 7, "project_name": "Website Redesign", "project_color": "#2D8CFF",
  "app_id": 2, "app_name": "Photoshop",
  "category_name": "Design",
  "start_timestamp": "2026-05-26T14:00:00Z",

  /* Screen-specific extras filled by the firmware so the dashboard can
     mirror the device's screen faithfully without a side fetch. */
  "weather":       { "city": "Bratislava", "temp_c": 23.2, "condition": "Partly cloudy" },
  "news_headline": "* Top story...",
  "idle_date":     "26.05.2026",
  "list_rows":     [ { "name": "Acme Corp", "color": "#FF8000" } ],
  "list_offset":   0,
  "list_count":    7,
  "toast_message": "Saved",
  "pomo_phase":    "focus",
  "pomo_left":     742
}
```

The `screen` string is one of
`boot | idle | client | project | category | app | running | confirm |
discard_confirm | settings | toast | sleep | reminder` (matching the device's
internal screen enum). On the `category` and `app` screens the `list_*`
extras carry the category list (or the in-category app list)
respectively, so the dashboard mirror can render the same rows the
device is showing.

The `project_color`, `category_name`, `weather`, `news_headline`,
`idle_date`, `list_*` and `toast_message` keys are only present when
their corresponding context is active (e.g. `category_name` shows up
once the user has picked a category; `idle_date` only on the idle
screen). `screen: "sleep"` keeps the underlying `state` value
(`running` / `paused` / `idle`) so dashboards still know what the
session is doing while the touch panel is dimmed.

`fw` is the firmware version (`FW_VERSION` in `config.h`). `queued` is the
number of sessions saved on the device while the server was unreachable;
they are re-sent once a minute while the device is idle. `ota_status` is
only present after an update request: `"waiting"` (held until no session
runs) or `"failed"`. `pomo_phase` (`focus` / `break` / `break_over`) and
`pomo_left` (seconds) appear on the running screen while pomodoro is on.

`language` (`"en"` / `"de"`) is the UI language the touch screen is
currently showing. The dashboard's remote-control mirror uses it to
render its labels in the same language, and `weather.condition` is
already localized by the firmware.

**Dashboard → server (subscribe)**

```json
{ "type": "subscribe" }
```

The server then broadcasts every device-state push it receives to all
subscribed dashboards, re-typed as `device_state`:

```json
{
  "type": "device_state",
  "hardware_id": "esp32_lixie_001",
  /* ...identical payload to the device push above... */
  "received_at": "2026-05-26T14:20:34Z"
}
```

The first device-state message after a (re)connect also triggers a replay
of any cached settings (`color`, `colon_color`, `brightness`,
`display_brightness`, `sleep_timeout_sec`, `sleep_on_idle`, `language`)
so a dashboard-driven setting survives the device dropping offline.

**Server → device (control)**

```json
{
  "type":               "settings",
  "color":              "#FF8000",
  "colon_color":        "#FF8000",
  "brightness":         150,
  "display_brightness": 100,
  "sleep_timeout_sec":  30,
  "sleep_on_idle":      false,
  "language":           "de",
  "pomodoro_min":       25,
  "break_min":          5,
  "reminder_min":       30,
  "night_start":        22,
  "night_end":          7,
  "night_brightness":   10
}
{ "type": "remote_touch", "x": 200, "y": 120, "pressed": true }
{ "type": "ota", "path": "/firmware/<token>.bin" }
```

A `settings` payload may include any subset of the keys above; the
firmware applies only the keys present. These are sent in response to
`PUT /devices/<id>/settings` and `POST /devices/<id>/remote/touch`
respectively.

---

## Error responses

```json
{ "error": "name is required" }
```

| Status | When |
|---|---|
| `400` | Missing required field, invalid reference, bad colour / coordinate / brightness range |
| `404` | Record not found for the given ID |
| `500` | Unexpected server error |

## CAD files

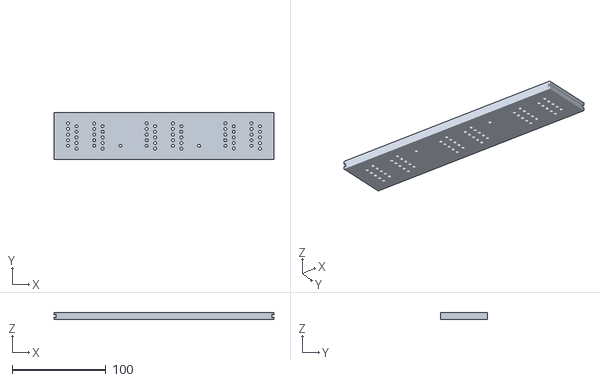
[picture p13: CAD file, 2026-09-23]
3d/glass-fullv2.stl
235.0 x 50.0 x 8.00

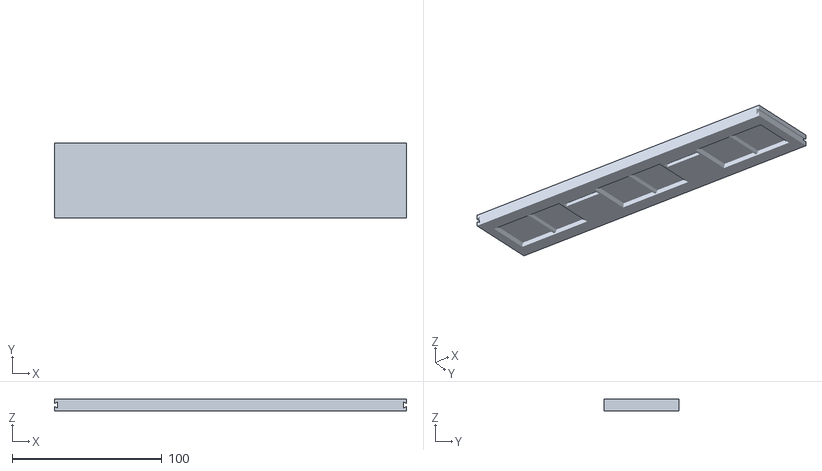
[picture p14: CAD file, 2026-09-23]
3d/glass-full-top-v2.stl
235.0 x 50.0 x 8.00

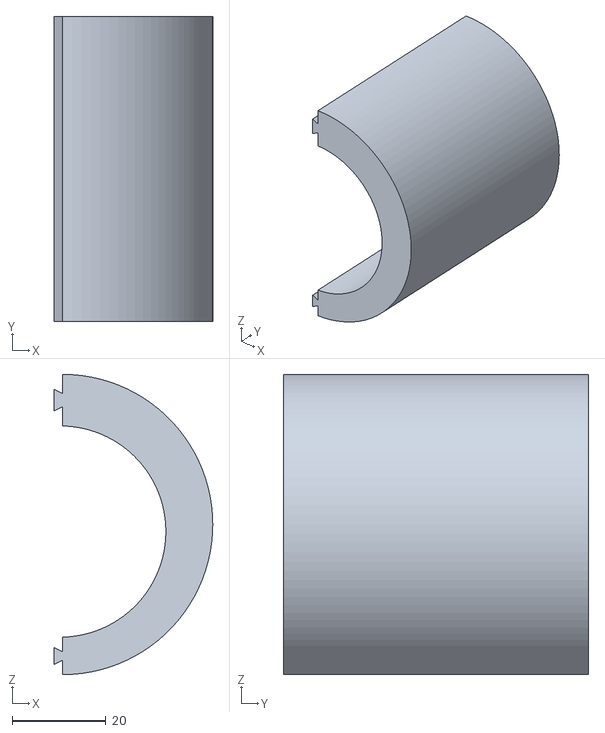
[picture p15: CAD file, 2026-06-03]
3d/esp-bootom-right.stl
33.8 x 65.0 x 64.0

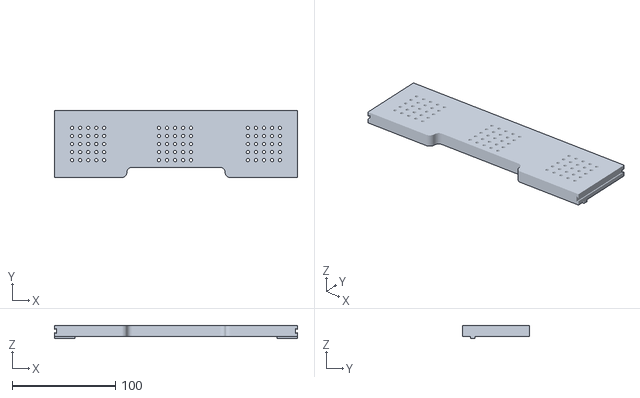
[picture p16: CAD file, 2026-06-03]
3d/esp-top.stl
235.0 x 65.0 x 13.0

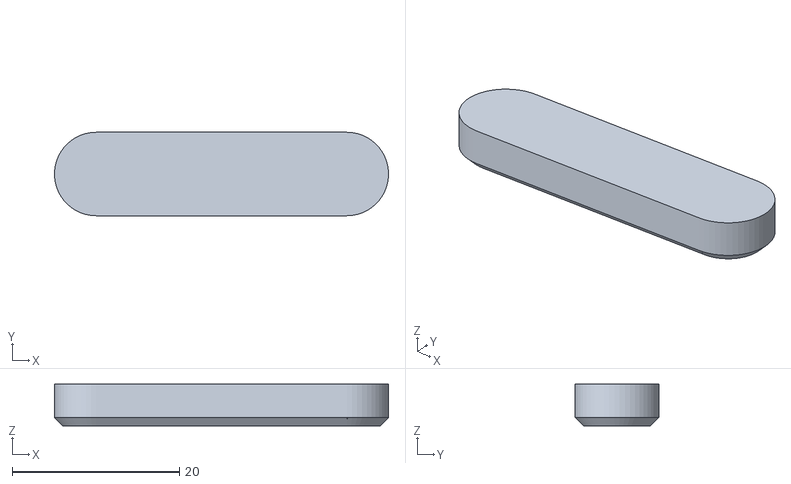
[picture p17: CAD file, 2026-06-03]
3d/foot.stl
40.0 x 10.00 x 5.00

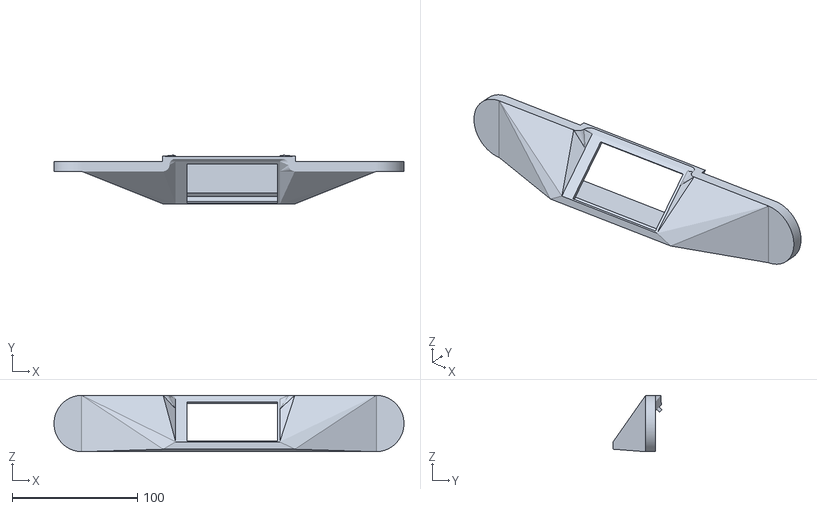
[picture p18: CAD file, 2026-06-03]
3d/display-lixie-final2.stl
279.0 x 39.0 x 45.0

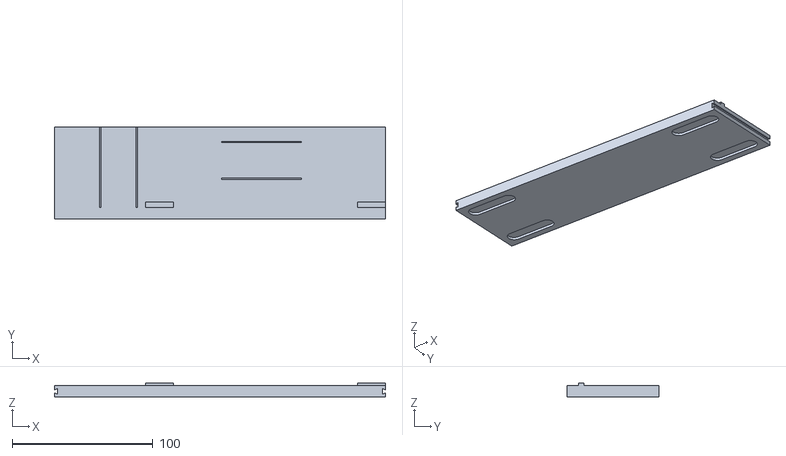
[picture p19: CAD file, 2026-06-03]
3d/esp-bootom-new.stl
235.0 x 65.0 x 9.89

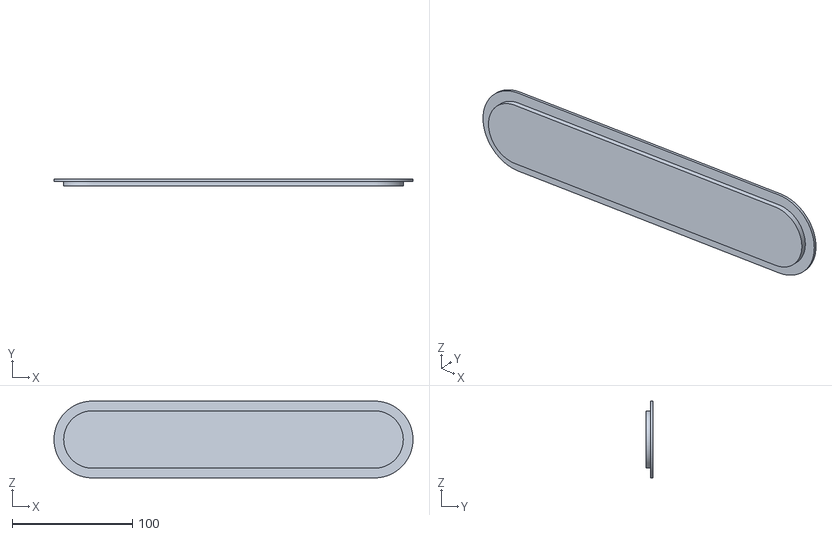
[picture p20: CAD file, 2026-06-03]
3d/numbers-backwall.stl
299.0 x 6.00 x 64.0

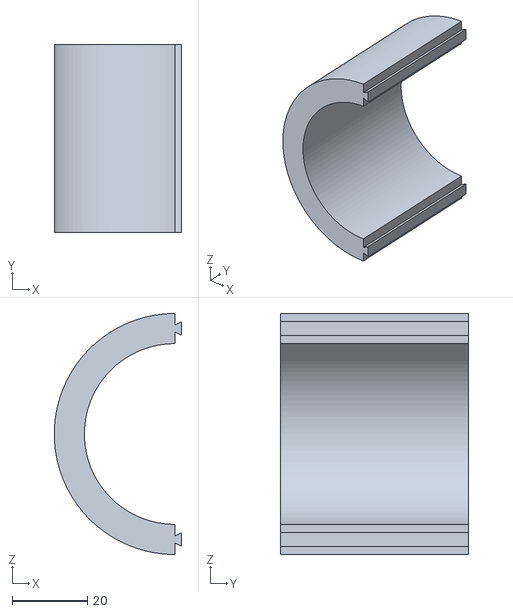
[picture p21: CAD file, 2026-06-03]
3d/glass-side2x.stl
33.8 x 50.0 x 64.0

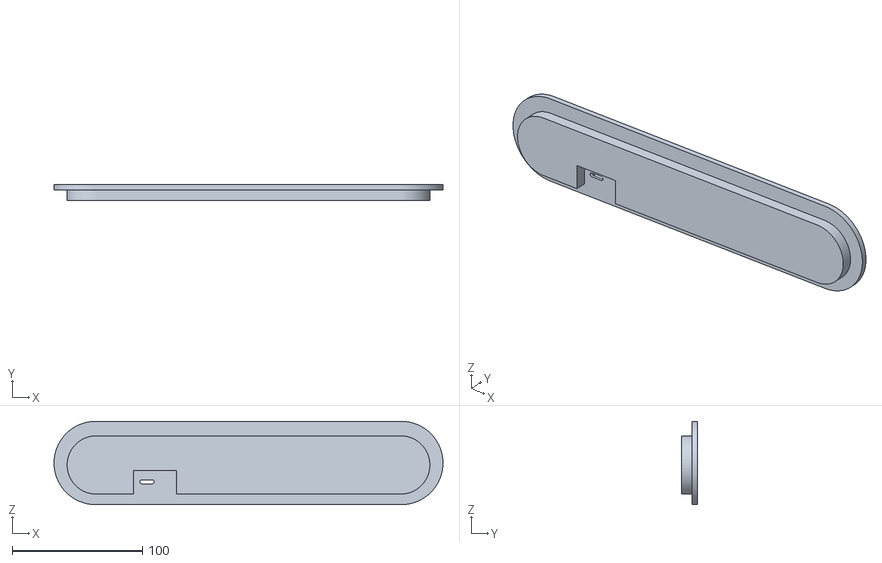
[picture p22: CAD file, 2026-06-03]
3d/esp-back-wall.stl
299.0 x 12.0 x 64.0

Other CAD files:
3d/esp-bootom-left.stl

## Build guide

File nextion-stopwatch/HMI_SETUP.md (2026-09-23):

# Nextion HMI setup — NX4024T032

The firmware draws **everything** at runtime via Nextion drawing commands
(`cls`, `fill`, `xstr`, `line`, etc.). The HMI file therefore only has to
provide the runtime fonts and a single empty page; no objects, no events.

> ⚠ **Required.** A brand-new display ships with a factory demo HMI that
> auto-runs an animation. That demo paints over our drawing commands and
> produces the "demo screen on top of the normal screen" symptom. You **must**
> upload the minimal HMI below at least once — after that, the demo is gone
> forever and our drawing commands own the framebuffer.

## 1. Create the HMI

1. Open Nextion Editor → **File ▸ New** → save as `lixie_stopwatch.HMI`.
2. **Settings ▸ Device** → pick `NX4024T032_011` (Basic, 400×240).
   Orientation: **Horizontal**.
3. Page 0 — leave empty. Background colour: `4258` (matches `COL_BG`).

## 2. Generate the four fonts

Use **Tools ▸ Font Generator** four times. Height is what matters; pick any
clean monospace or sans-serif font installed on your PC.

| Slot | Suggested font | Height | Used for |
|---|---|---|---|
| 0 | Arial | 16 px  | small captions, hints |
| 1 | Arial | 24 px  | titles, list rows |
| 2 | Arial Bold | 40 px  | section headings, STOP  |
| 3 | DSEG7 / Bahnschrift  | 64 px  | the running stopwatch |

After each generation, **Add Font** so they receive IDs `0..3` in that
order. Keep the default **ASCII** charset — the firmware transliterates
everything it draws to 7-bit ASCII (`utf8cp1250.cpp`), and the built-in
German translation (`lang.cpp`) is written without umlauts ("Zurueck",
"waehlen") for the same reason. The firmware references them via `config.h`:
`FONT_SMALL` / `FONT_MEDIUM` / `FONT_LARGE` / `FONT_HUGE`.

## 3. Page 0 preinitialise event

Open `Page0` → **Preinitialize Event** and paste:

```
bauds=115200
sendxy=1
bkcmd=0
cls 4258
```

`bauds=` persists across power cycles. `sendxy=1` makes the panel report
raw touch coordinates (`0x67 X Y ev FF FF FF`), which the firmware parses
in `Nextion::poll()`. `bkcmd=0` silences acknowledgement frames we never
read.

## 4. Compile & upload

1. **File ▸ TFT File Output** → save the `.tft`.
2. Copy onto a FAT32 microSD card (the file must be the only `.tft` on
   the card), insert into the display while powered off, power on. The
   display flashes the firmware automatically.
3. Eject the card and reboot the display.

## 5. Wiring to ESP32-S3 (N16R8)

```
NX4024T032 pin   ESP32-S3-N16R8
─────────────    ───────────────
+5V              5V   (USB-C from the dev board is enough)
GND              GND
TX               GPIO18  (RX1)
RX               GPIO17  (TX1)
```

> GPIO19/20 are reserved for native USB on the N16R8 — using them for
> UART kills the USB-CDC serial console. GPIO17/18 are free
> general-purpose pins.

Power both from the same 5 V rail and tie the grounds together. At the
default low/medium brightness the USB-C input is plenty; if you want to
run all 75 LEDs at full brightness with the display, switch to an
external 5 V / 5 A+ supply (see the main README for power notes).

## 6. First boot

On a brand-new display the factory baud is 9600. The firmware bootstraps
by sending `bauds=115200` at 9600, then switches its own UART to 115200.
After the first successful run the display remembers 115200 and
subsequent boots are immediate.

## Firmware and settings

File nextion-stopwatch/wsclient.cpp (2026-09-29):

#include "wsclient.h"
#include "config.h"
#include "ui.h"
#include "settings.h"
#include "lang.h"
#include "api.h"
#include "wifimgr.h"
#include <WiFi.h>
#include <WebSocketsClient.h>
#include <HTTPUpdate.h>
#include <ArduinoJson.h>

static WebSocketsClient ws;
static bool     sConnected     = false;
static uint32_t sLastPushMs    = 0;
static const char* sLastStateName  = "";   // detect changes for immediate push
static const char* sLastScreenName = "";   // finer-grained change detection

// Firmware update requested by the dashboard. sOtaPath is relative to
// WifiMgr::apiBase(); sOtaStatus is reported in every state push ("" = nothing
// to report, "waiting" = queued until the session ends, "failed").
static String sOtaPath;
static String sOtaStatus;

// Read an integer setting and clamp it to [lo, hi]. Returns false if the
// key is missing or not a number.
static bool readInt(JsonDocument& doc, const char* key, int lo, int hi, int& out) {
    if (!doc[key].is<int>()) return false;
    out = doc[key].as<int>();
    if (out < lo) out = lo;
    if (out > hi) out = hi;
    return true;
}

static void onEvent(WStype_t type, uint8_t* payload, size_t length) {
    switch (type) {
        case WStype_CONNECTED:
            sConnected = true;
            Serial.println("[ws] connected");
            break;
        case WStype_DISCONNECTED:
            sConnected = false;
            Serial.println("[ws] disconnected");
            break;
        case WStype_ERROR:
            Serial.printf("[ws] error len=%u\n", (unsigned)length);
            break;
        case WStype_TEXT: {
            // Server → device control. Settings message shape (all fields
            // optional, any subset may be present):
            //   { "type": "settings",
            //     "color":              "#RRGGBB",   // clock/stopwatch digits
            //     "colon_color":        "#RRGGBB",   // the two dots
            //     "clock_style":        "d:...|c:..."// per-digit / cycle, "" = off
            //     "demo":               bool,        // showcase animation
            //     "brightness":         0..255,      // LED matrix brightness
            //     "display_brightness": 0..100,      // Nextion backlight %
            //     "sleep_timeout_sec":  0..65535,    // 0 disables auto-sleep
            //     "sleep_on_idle":      bool,       // sleep from idle too
            //     "language":           "en"|"de",   // Nextion UI language
            //     "pomodoro_min":       0..120,      // focus block (0 = off)
            //     "break_min":          1..60,
            //     "reminder_min":       0..480,      // idle reminder (0 = off)
            //     "night_start":        0..23,       // night mode window
            //     "night_end":          0..23,
            //     "night_brightness":   0..255 }
            // Firmware update: { "type": "ota", "path": "/firmware/<token>.bin" }
            JsonDocument doc;
            DeserializationError err = deserializeJson(doc, payload, length);
            if (err) {
                Serial.printf("[ws] bad msg: %s\n", err.c_str());
                break;
            }
            const char* msgType = doc["type"] | "";
            if (strcmp(msgType, "settings") == 0) {
                if (doc["color"].is<const char*>()) {
                    Settings::setClockColorHex(doc["color"].as<String>());
                }
                if (doc["colon_color"].is<const char*>()) {
                    Settings::setColonColorHex(doc["colon_color"].as<String>());
                }
                if (doc["clock_style"].is<const char*>()) {
                    Settings::setClockStyle(doc["clock_style"].as<String>());
                }
                if (doc["demo"].is<bool>()) {
                    Settings::setDemo(doc["demo"].as<bool>());
                }
                if (doc["brightness"].is<int>()) {
                    int b = doc["brightness"].as<int>();
                    if (b < 0)   b = 0;
                    if (b > 255) b = 255;
                    Settings::setBrightness((uint8_t)b);
                }
                if (doc["display_brightness"].is<int>()) {
                    int p = doc["display_brightness"].as<int>();
                    if (p < 0)   p = 0;
                    if (p > 100) p = 100;
                    Settings::setDisplayBrightness((uint8_t)p);
                }
                if (doc["sleep_timeout_sec"].is<int>()) {
                    int s = doc["sleep_timeout_sec"].as<int>();
                    if (s < 0)     s = 0;
                    if (s > 65535) s = 65535;
                    Settings::setSleepTimeoutSec((uint16_t)s);
                }
                if (doc["sleep_on_idle"].is<bool>()) {
                    Settings::setSleepOnIdle(doc["sleep_on_idle"].as<bool>());
                }
                if (doc["language"].is<const char*>()) {
                    Language l = Lang::fromCode(doc["language"].as<const char*>());
                    if (l != Settings::language()) {
                        Settings::setLanguage(l);
                        UI::redraw();   // repaint the current screen in the new language
                    }
                }
                int v;
                if (readInt(doc, "pomodoro_min",     0, 120, v)) Settings::setPomodoroMin((uint8_t)v);
                if (readInt(doc, "break_min",        1, 60,  v)) Settings::setBreakMin((uint8_t)v);
                if (readInt(doc, "reminder_min",     0, 480, v)) Settings::setReminderMin((uint16_t)v);
                if (readInt(doc, "night_start",      0, 23,  v)) Settings::setNightStart((uint8_t)v);
                if (readInt(doc, "night_end",        0, 23,  v)) Settings::setNightEnd((uint8_t)v);
                if (readInt(doc, "night_brightness", 0, 255, v)) Settings::setNightBrightness((uint8_t)v);
                Serial.printf("[ws] settings applied clock=%s colon=%s bright=%u disp=%u sleep=%u idle=%d lang=%s\n",
                              Settings::clockColorHex().c_str(),
                              Settings::colonColorHex().c_str(),
                              Settings::brightness(),
                              Settings::displayBrightness(),
                              Settings::sleepTimeoutSec(),
                              (int)Settings::sleepOnIdle(),
                              Lang::code(Settings::language()));
            } else if (strcmp(msgType, "ota") == 0) {
                const char* path = doc["path"] | "";
                if (path[0] == '/') {
                    sOtaPath   = path;
                    sOtaStatus = "waiting";
                    Serial.printf("[ota] requested %s\n", path);
                }
            } else if (strcmp(msgType, "remote_touch") == 0) {
                // Remote control — inject a synthetic touch as if the user
                // had pressed/released the physical Nextion at (x,y).
                int  x       = doc["x"]       | -1;
                int  y       = doc["y"]       | -1;
                bool pressed = doc["pressed"] | true;
                if (x >= 0 && y >= 0) {
                    UI::injectTouch(x, y, pressed);
                    Serial.printf("[ws] remote touch x=%d y=%d %s\n",
                                  x, y, pressed ? "down" : "up");
                }
            }
            break;
        }
        default:
            break;
    }
}

static void pushState() {
    if (!sConnected) return;

    UI::LiveSnapshot s = UI::getLiveSnapshot();

    JsonDocument doc;
    doc["type"]            = "state";
    doc["hardware_id"]     = HARDWARE_ID;
    doc["state"]           = s.state;
    doc["screen"]          = s.screen;
    doc["paused"]          = s.paused;
    doc["elapsed_seconds"] = s.elapsedSec;
    // Lets the dashboard mirror render its labels in the same language as
    // the physical screen.
    doc["language"]        = Lang::code(Settings::language());
    doc["fw"]              = FW_VERSION;
    doc["queued"]          = Api::queuedCount();
    if (sOtaStatus.length()) doc["ota_status"] = sOtaStatus;
    if (s.clientId >= 0) {
        doc["client_id"]    = s.clientId;
        doc["client_name"]  = s.clientName;
        doc["client_color"] = s.clientColor;
    }
    if (s.projectId >= 0) {
        doc["project_id"]    = s.projectId;
        doc["project_name"]  = s.projectName;
        doc["project_color"] = s.projectColor;
    }
    if (s.appId >= 0) {
        doc["app_id"]   = s.appId;
        doc["app_name"] = s.appName;
    }
    if (s.categoryName.length()) {
        doc["category_name"] = s.categoryName;
    }
    if (s.startIso.length()) {
        doc["start_timestamp"] = s.startIso;
    }

    // Screen-specific extras (list rows, weather, news, toast text...) so the
    // dashboard remote can render a faithful mirror without a side fetch.
    UI::writeStateExtras(doc);

    String body;
    serializeJson(doc, body);
    ws.sendTXT(body);
    sLastStateName  = s.state;
    sLastScreenName = s.screen;
}

namespace WsClient {

void begin() {
    ws.begin(WifiMgr::serverHost(), WifiMgr::serverPort(), WS_PATH);
    ws.onEvent(onEvent);
    ws.setReconnectInterval(5000);
    // Liveness pings — sent every 15 s, disconnect if no pong in 3 attempts.
    ws.enableHeartbeat(15000, 3000, 2);
}

void loop() {
    ws.loop();

    if (WiFi.status() != WL_CONNECTED) return;

    UI::LiveSnapshot s = UI::getLiveSnapshot();
    bool isActive = (strcmp(s.state, "running") == 0 ||
                     strcmp(s.state, "paused")  == 0 ||
                     strcmp(s.state, "confirm") == 0);
    uint32_t interval = isActive ? 1000UL : 5000UL;

    uint32_t now = millis();
    bool stateChanged  = (sLastStateName  && strcmp(sLastStateName,  s.state)  != 0);
    bool screenChanged = (sLastScreenName && strcmp(sLastScreenName, s.screen) != 0);

    // Push immediately on any state or screen transition so the remote-
    // control UI mirrors the device within one tick of the user's action.
    if (stateChanged || screenChanged || now - sLastPushMs >= interval) {
        sLastPushMs = now;
        pushState();
    }
}

bool isConnected() { return sConnected; }

void runPendingOta() {
    if (!sOtaPath.length()) return;
    // Never interrupt a session; install once the device is back home.
    UI::Screen scr = UI::current();
    if (UI::sessionActive() || (scr != UI::SCR_IDLE && scr != UI::SCR_SLEEP)) return;
    if (WiFi.status() != WL_CONNECTED) return;

    String url = WifiMgr::apiBase() + sOtaPath;
    sOtaPath = "";
    Serial.printf("[ota] installing from %s\n", url.c_str());
    UI::showBootMessage(TR(S_UPDATING));

    // The server sends an x-MD5 header, which HTTPUpdate checks before it
    // switches partitions — a truncated download never boots.
    WiFiClient client;
    httpUpdate.rebootOnUpdate(true);
    httpUpdate.update(client, url);

    // Only reached when the update did not happen.
    Serial.printf("[ota] failed: %s\n", httpUpdate.getLastErrorString().c_str());
    sOtaStatus = "failed";
    UI::toast(TR(S_UPDATE_FAILED), 2500, UI::SCR_IDLE);
}

}  // namespace WsClient

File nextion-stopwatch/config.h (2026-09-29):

// This file is the single place where you configure:
//   - which ESP32 pins are connected to the Nextion display and LED strip
//   - WiFi SSID and password
//   - server address (API)
//   - colors, font sizes, NTP servers, etc.
// Anyone wiring up the hardware must edit WIFI_SSID, WIFI_PASSWORD,
// WS_HOST / WS_PORT (or set them on the Wi-Fi setup page) and HARDWARE_ID.
// ============================================================================

#ifndef CONFIG_H
#define CONFIG_H

// Hardware pins

#define NEXTION_TX_PIN   17         //display
#define NEXTION_RX_PIN   18         //display
#define NEXTION_UART_NUM 1
#define NEXTION_BAUD     115200   // target speed after bootstrap
#define NEXTION_DEFAULT_BAUD 9600 // Nextion factory default

// Display geometry (NX4024T032 = 400 x 240 px, landscape)
#define DISP_W  400
#define DISP_H  240

// 6 digit matrices (10 LEDs each) + 2 colon LEDs = 62 LEDs total.
// Wired as a single chain on GPIO5.
#define LED_PIN          5
#define LED_NUM          75
#define LED_BRIGHTNESS   250          // 0..255 — keep modest for current draw
#define LED_COLON_LEFT   27
#define LED_COLON_RIGHT  32

// WiFi / API
// These are the *factory defaults* — they're tried only when no credentials
// have been saved via the on-device web setup page yet. After the first
// successful provisioning the saved (NVS) credentials take precedence.

#define WIFI_SSID     "changeme"
#define WIFI_PASSWORD "changeme"

// Soft-AP that comes up when the ESP32 can't connect to any known network.
// Connect a phone to it, then browse to http://192.168.4.1 to configure.
#define AP_SSID                 "LixieStopWatch-Setup"
#define AP_PASSWORD             ""           // empty = open AP
#define WIFI_CONNECT_TIMEOUT_MS 15000UL      // give up on station mode after this

// Dashboard server — factory defaults only. The captive setup page can
// override host and port (saved in NVS); see WifiMgr::serverHost().
// REST lives at http://<host>:<port>/api/v1, the WebSocket at WS_PATH.
#define WS_HOST       "192.168.137.233"
#define WS_PORT       5000
#define WS_PATH       "/api/v1/ws"

// Identifier this device sends in POST /timelogs (auto-registers a row in `device`).
#define HARDWARE_ID   "esp32_lixie_001"

// Shown on the dashboard's Devices page. Bump it for every build you push
// over the air so you can see which devices already run the new image.
#define FW_VERSION    "2.0.0"

// Sessions that could not reach the server are kept in NVS and retried
// once a minute while idle. NVS strings max out at ~4 KB, which fits
// about this many entries.
#define OFFLINE_QUEUE_MAX 16

// ============================================================================
// Idle-screen content sources (weather + news headlines)
// ============================================================================
// Weather location is derived from the device's public IP via ip-api.com,
// then current conditions are pulled from Open-Meteo. No API key required.
// RSS feed for the rotating headline at the bottom of the idle screen.
//   Swap freely. https URLs are supported (TLS via setInsecure()).
#define NEWS_RSS_URL "https://www.theverge.com/rss/tech/index.xml"
#define WEATHER_REFRESH_MS  (60UL * 60UL * 1000UL)   // 1 hour
#define NEWS_REFRESH_MS     (15UL * 60UL * 1000UL)
#define NEWS_ROTATE_MS      8000UL

// Used when ip-api.com geolocation fails (corporate networks, VPNs, rate
// limits). Defaults to Bratislava so we still show a sane weather strip.
#define WEATHER_FALLBACK_CITY "Bratislava"
#define WEATHER_FALLBACK_LAT  48.1486f
#define WEATHER_FALLBACK_LON  17.1077f

// ============================================================================
// NTP
// ============================================================================
#define NTP_SERVER_1  "pool.ntp.org"
#define NTP_SERVER_2  "time.google.com"
// Europe/Bratislava — CET (UTC+1 winter) / CEST (UTC+2 summer DST).
// Note: in POSIX TZ syntax the sign is inverted; "CET-1" means "CET is one
// hour AHEAD of UTC" (i.e. UTC+1). DST switches last Sun of Mar / last Sun of Oct.
#define TZ_STRING     "CET-1CEST,M3.5.0,M10.5.0/3"

// UI

#define FONT_SMALL    0   // ~16 px
#define FONT_MEDIUM   1   // ~24 px
#define FONT_LARGE    2   // ~40 px
#define FONT_HUGE     3   // ~64 px digits for the timer

// 16-bit RGB565 colour palette.
#define COL_BLACK     0x0000
#define COL_WHITE     0xFFFF
#define COL_BG        0x10A2  // very dark blue-grey
#define COL_PANEL     0x2104  // panel surface
#define COL_TEXT      0xFFFF
#define COL_MUTED     0xAD75  // grey text
#define COL_ACCENT    0xFB00  // Lixie orange (#FF8000)
#define COL_GREEN     0x07E0
#define COL_RED       0xF800
#define COL_BLUE      0x2D9F
#define COL_GREY      0x6B4D  // #6B6B6B — pause-button neutral

#endif

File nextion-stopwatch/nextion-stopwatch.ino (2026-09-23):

// Main program for the ESP32.
// setup():
//   - initialises the Nextion display, shows "Booting..."
//   - initialises the LED matrix (LedDisplay::begin)
//   - connects to WiFi, syncs time via NTP
//   - switches to the main idle screen (SCR_IDLE)
// loop():
//   - collects touches from Nextion and forwards them to UI::handleTouch
//   - calls UI::tick() and LedDisplay::tick() to refresh screen and matrix
//   - short delay (20 ms)
// ============================================================================

#include <WiFi.h>
#include <time.h>

#include "config.h"
#include "nextion.h"
#include "ui.h"
#include "leddisplay.h"
#include "weather.h"
#include "news.h"
#include "api.h"
#include "wifimgr.h"
#include "wsclient.h"
#include "settings.h"
#include "lang.h"

static void enterApSetupMode() {
    UI::showBootMessage(String(TR(S_AP_SETUP_1)) + "\n"
                        + TR(S_AP_SETUP_2) + AP_SSID + "'\n"
                        + TR(S_AP_SETUP_3));
    Serial.println("[boot] AP setup loop");
    // Stay here forever — the only escape is the user saving credentials,
    // which calls ESP.restart() inside the captive portal handler.
    while (true) {
        WifiMgr::loop();
        delay(5);
    }
}

static void syncNtp() {
    Serial.println("[ntp] sync...");
    UI::showBootMessage(TR(S_NTP_SYNCING));
    configTzTime(TZ_STRING, NTP_SERVER_1, NTP_SERVER_2);
    uint32_t t0 = millis();
    time_t now = 0;
    while ((now = time(nullptr)) < 100000 && millis() - t0 < 8000) {
        delay(200);
    }
    Serial.printf("[ntp] %s\n", now > 100000 ? "synced" : "timeout");
}

void setup() {
    Serial.begin(115200);
    delay(50);
    Serial.println("\n=== Lixie StopWatch — Nextion edition ===");

    Serial.println("[boot] init leds...");
    Serial.flush();
    LedDisplay::begin();
    Settings::begin();   // applies saved colour + brightness over defaults
    Serial.println("[boot] leds ok");
    Serial.flush();

    Serial.println("[boot] init nextion (will reassign GPIO17/18)...");
    Serial.flush();
    Nextion::begin();
    Serial.println("[boot] nextion ok");
    Serial.flush();

    UI::showBootMessage(TR(S_BOOTING));

    UI::showBootMessage(TR(S_WIFI_CONNECTING));
    if (!WifiMgr::begin()) {
        // Saved + default credentials both failed → captive portal.
        enterApSetupMode();   // never returns
    }
    UI::showBootMessage(TR(S_WIFI_OK) + WiFi.localIP().toString());
    syncNtp();

    Serial.println("[feed] initial weather + news fetch...");
    Serial.flush();
    Weather::refresh();
    News::refresh();
    Serial.printf("[feed] weather=%s news=%d\n",
                  Weather::get().valid ? "ok" : "miss", News::count());

    WsClient::begin();
    Serial.println("[ws] client started");

    Serial.println("[boot] entering idle");
    UI::goTo(UI::SCR_IDLE);
}

// Night dimming, offline-queue retries and pending firmware updates.
static void backgroundJobs() {
    static uint32_t lastNight = 0;
    static uint32_t lastQueue = 0;
    uint32_t now = millis();

    // Skip on the settings screen so its live brightness preview sticks.
    if (now - lastNight >= 1000 && UI::current() != UI::SCR_SETTINGS) {
        lastNight = now;
        Settings::applyNightMode(UI::sessionActive());
    }
    // Retry sessions saved while offline — only while idle, because each
    // attempt is a blocking HTTP call.
    if (now - lastQueue >= 60000UL && UI::current() == UI::SCR_IDLE) {
        lastQueue = now;
        Api::flushQueue();
    }
    WsClient::runPendingOta();
}

static void refreshFeeds() {
    static uint32_t lastWeather = 0;
    static uint32_t lastNews    = 0;

    // Only do blocking HTTP work while idle, to keep stopwatch ticks tight.
    if (UI::current() != UI::SCR_IDLE) return;

    uint32_t now = millis();
    if (now - lastWeather > WEATHER_REFRESH_MS) {
        lastWeather = now;
        Weather::refresh();
    }
    if (now - lastNews > NEWS_REFRESH_MS) {
        lastNews = now;
        News::refresh();
    }
}

void loop() {
    NextionTouch t;
    while (Nextion::poll(t)) {
        UI::handleTouch(t);
    }

    UI::tick();
    LedDisplay::tick();
    refreshFeeds();
    backgroundJobs();
    // WebSocket replaces the old HTTP heartbeat — every state push refreshes
    // last_seen on the server, so the dashboard's Online indicator stays
    // accurate without a second channel.
    WsClient::loop();

    delay(20);
}

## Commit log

2026-05-28 ledmap + communication
2026-05-28 working not working (old)
    [api.cpp, config.h]
2026-05-29 Fixed display, add weather, rss, fixed time
    [api.cpp, config.h, news.cpp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]
2026-05-29 Edited discard button function
2026-05-29 Added date and home button to the display
2026-06-01 Fixed light and added separate colours
    [config.h, nextion-stopwatch.ino]
2026-06-03 Public release
    [display-lixie-final2.stl, esp-back-wall.stl, esp-bootom-left.stl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]
2026-09-17 First test
    [glass-full-top-v2.stl, glass-fullv2.stl]
